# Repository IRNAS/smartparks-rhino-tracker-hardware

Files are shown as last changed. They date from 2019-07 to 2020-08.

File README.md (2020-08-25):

# Smart Parks Rhino Tracker Hardware
 

<br>

Device is composed from 3 different PCBs thah are stacked in to box like shape.

Stackup of PCBs is in this order:
- GPS (Top PCB)					Size: 28mm x 20mm 
- MCU (Side PCB)				Size: 28mm x 20mm (After final assembly)
- LORA ANTENNA (Side PCB)		Size: 28mm x 15.5mm
- BATTERY (Between side PCBs)

PCB specifications:
- 0.8mm PCB thinknes
- 0.152mm (6mil) trace to trace and trace to polygon clearance
- 0.75mm RF line thinknes

Connections between PCBs:
- MCU -> GPS - Solder pads on each PCB
- MCU -> LORA antenna - Coaxial cable

Assebled view
 
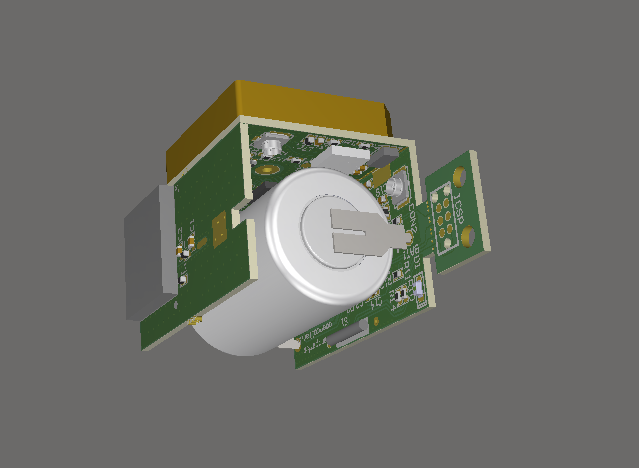
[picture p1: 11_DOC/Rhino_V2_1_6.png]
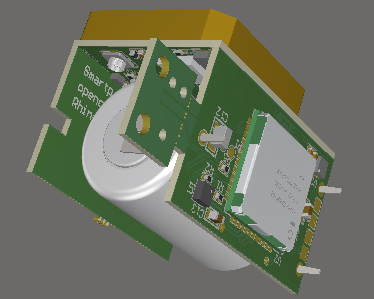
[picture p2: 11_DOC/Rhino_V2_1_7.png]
						

Exploded view
 
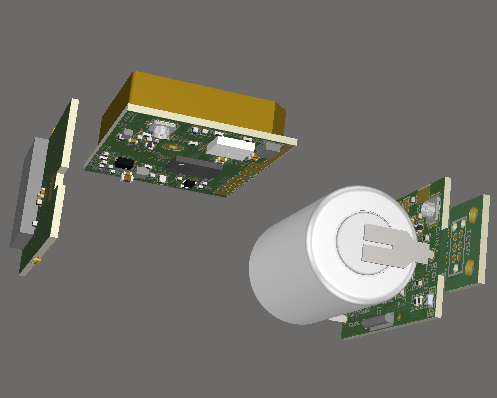
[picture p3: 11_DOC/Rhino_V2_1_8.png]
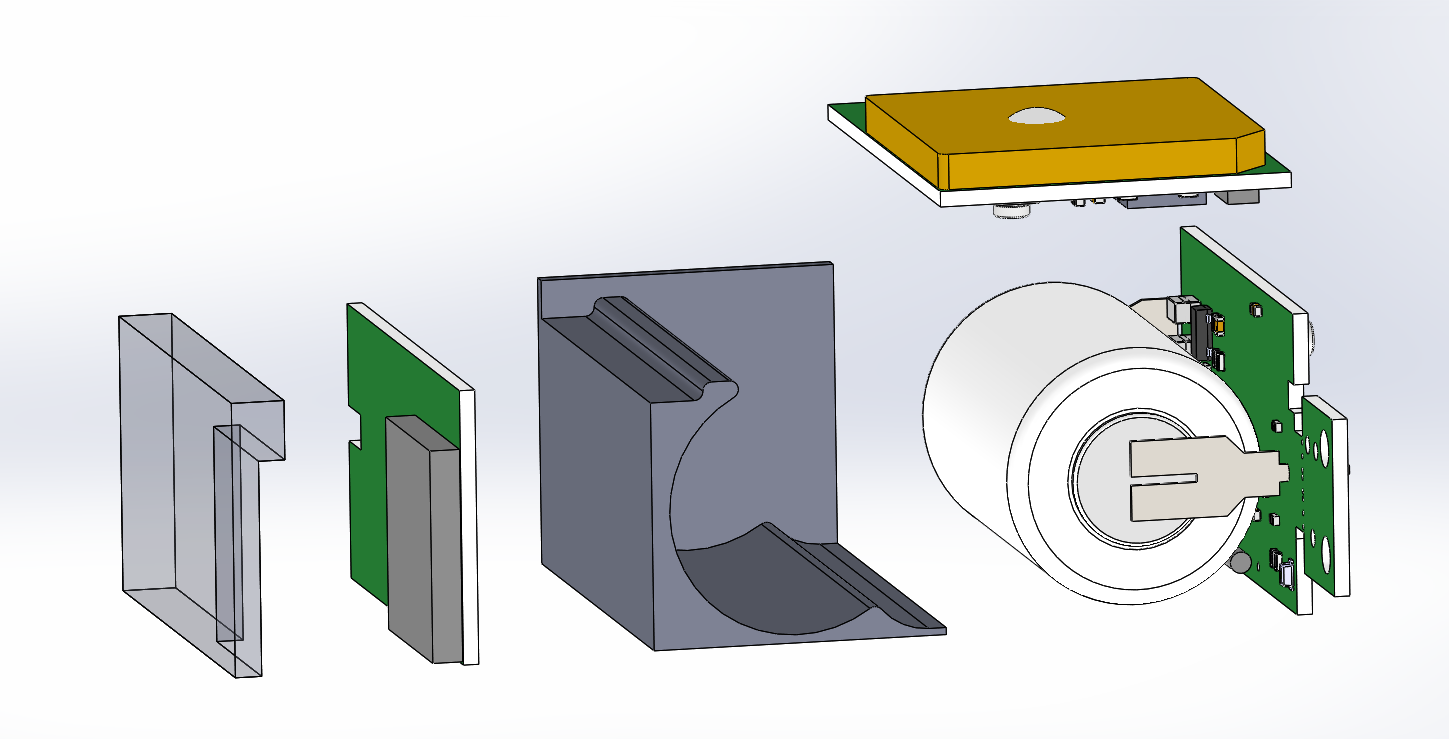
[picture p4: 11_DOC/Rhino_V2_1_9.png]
			

Future changes:
- GPS
	- Reposition of GPS antenna to the center of the PCB
	- Better power supply for GPS (Lower working voltage)
	- Improve GND polygon for better GPS antenna performance	
	
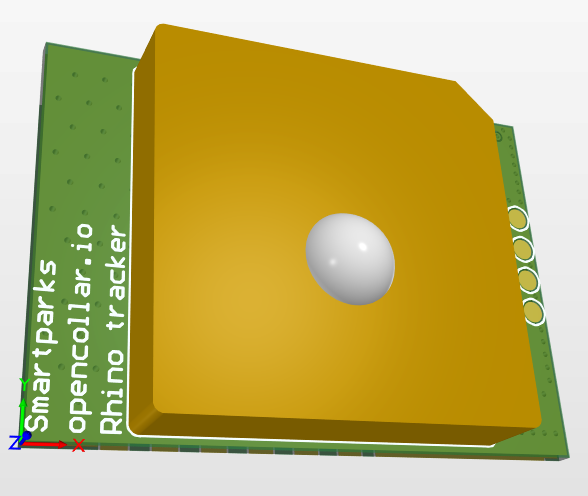
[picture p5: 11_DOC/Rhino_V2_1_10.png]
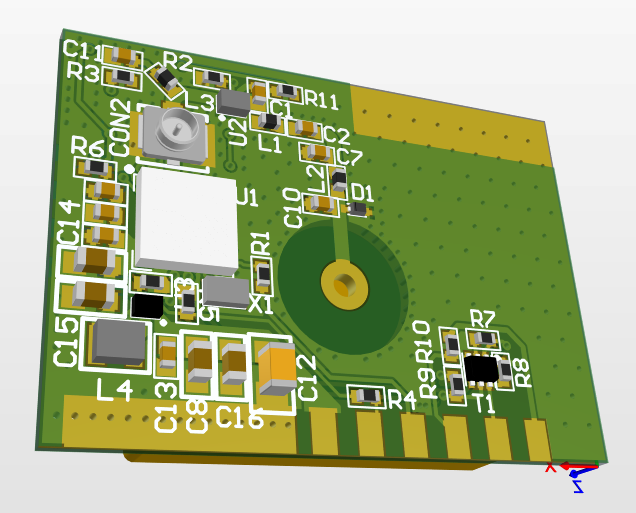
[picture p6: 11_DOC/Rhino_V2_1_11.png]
						

- MCU
	- Optimize track path for antenna
	- Change PCB orientation in final assembly like so that MCU is under battery
	- Optimize hardware for battery voltage measure
	- Move REED switch closer to the MCU
	
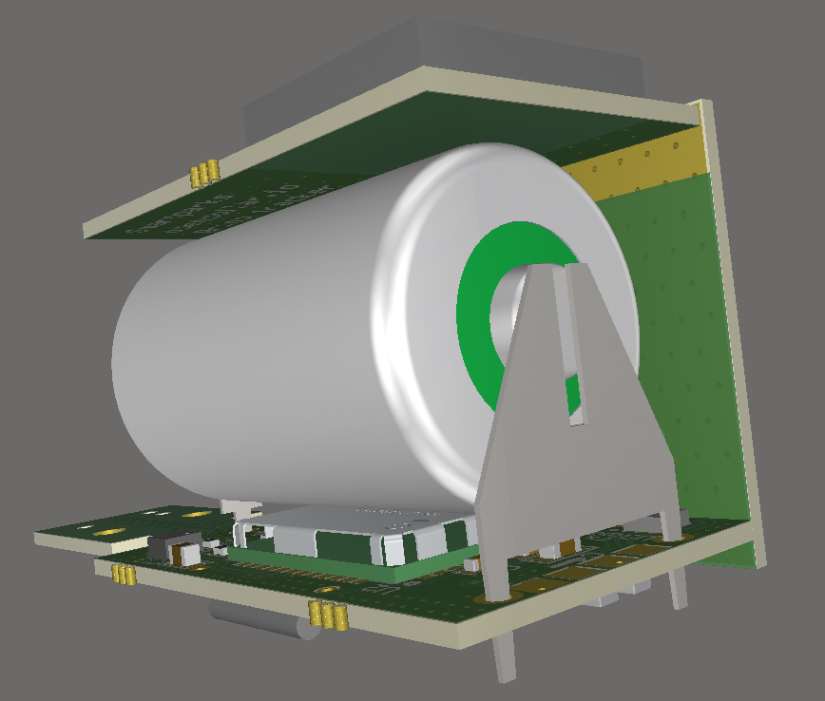
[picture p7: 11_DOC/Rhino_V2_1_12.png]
		
		
- LORA ANTENNA
	- Component value optimization for better antenna performance
 	
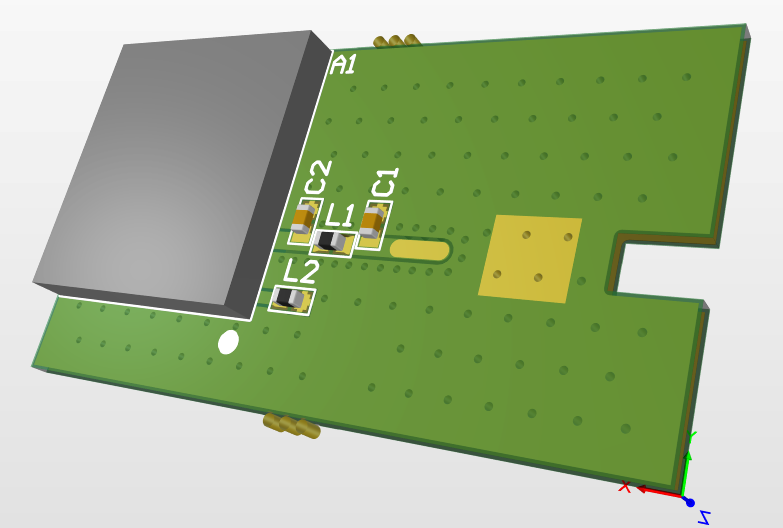
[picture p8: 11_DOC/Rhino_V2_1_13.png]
		

- Mehanical Specification:
	- Device dimensions 32x24x27mm
	- Device weight: ~30g
	- Device is put in polyurethane resin to protect it (https://electrolube.com/product/ur5528-chemically-resistant-polyurethane-resin/)
	- Inside of the device and around the battery there is pa peace of plastic for:
		- Keeping the gap between battery na LORA antenna eqalu on all devices assebled
		- Preventing the resin to go under the MCU metal case (There was a problem with RF radio when resin came under matel case of MCU)
		- Preventing the resin to go under GPS BGA chip (There was a problem when resin came under BGA and coused cold solder joints)
	- Resin thinknes arount the device is 2mm	

Currently under development, for all information see the [schematic PDF file](https://github.com/IRNAS/smartparks-rhino-tracker-hardware/blob/master/10_OUTPUT_FILES/).Produced board versions can be found in the [release section](https://github.com/IRNAS/smartparks-rhino-tracker-hardware/releases) of the repository.

**Latest release: [v2.5](https://github.com/IRNAS/smartparks-rhino-tracker-hardware)**

All comments and suggestions can be added to the [Issues]() section of the repo. For additional details see the [Issue]() section.

---

## Licensing

Rhino tracker hardware with documentation is licensed under [CERN OHL v.1.2. license](https://www.ohwr.org/licenses/cern-ohl/license_versions/v1.2).

What this means is that you can use this hardware and documentation without paying a royalty and knowing that you'll be able to use your version forever. You are also free to make changes but if you share these changes then you have to do so on the same conditions that you enjoy.

IRNAS is name and mark of Institute IRNAS Rače. You may use these name and terms only to attribute the appropriate entity as required by the Open Licence referred to above. You may not use them in any other way and in particular you may not use them to imply endorsement or authorization of any hardware that you design, make or sell.

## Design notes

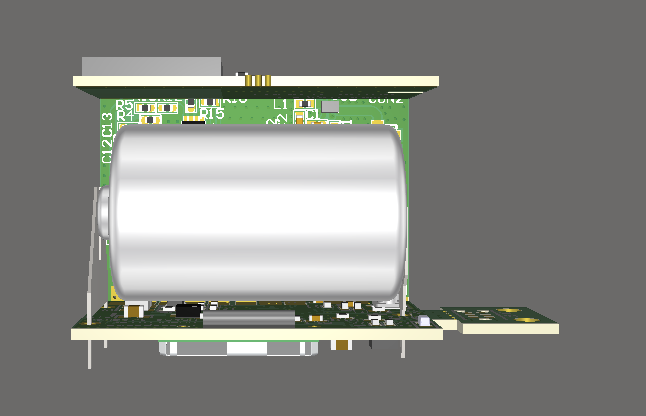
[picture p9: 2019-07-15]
11_DOC/Rhino_V2_1_1.png

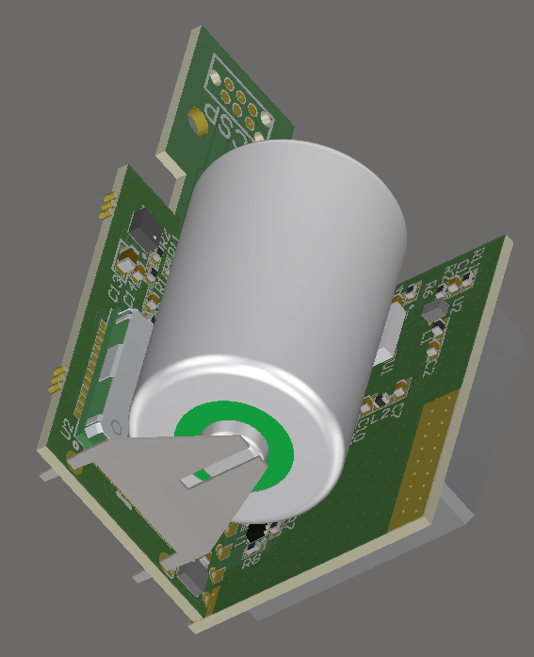
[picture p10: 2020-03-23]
11_DOC/Rhino Tracker 1.png

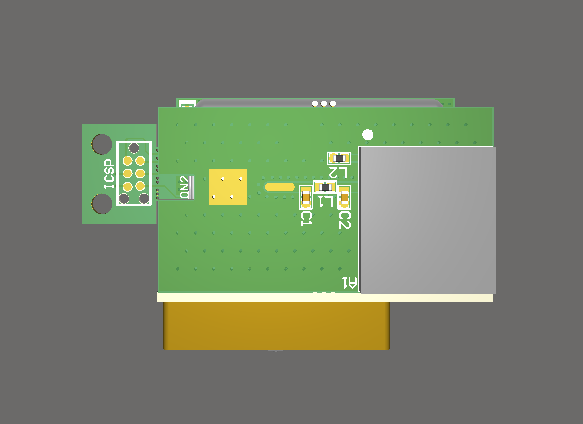
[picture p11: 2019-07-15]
11_DOC/Rhino_V2_1_5.png

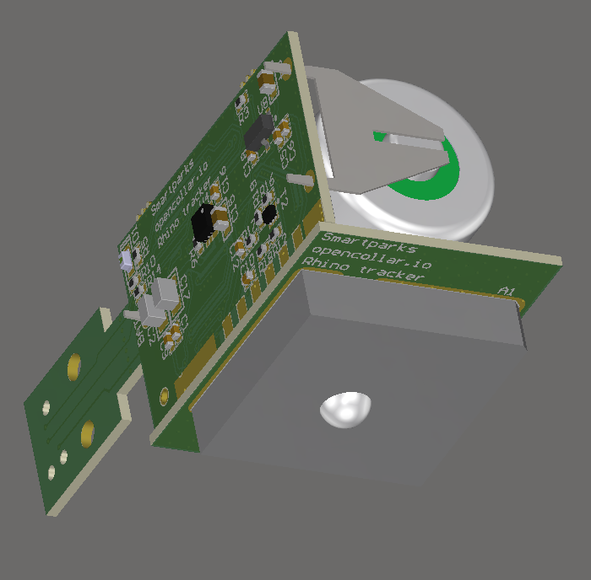
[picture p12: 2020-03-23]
11_DOC/Rhino Tracker 2.png

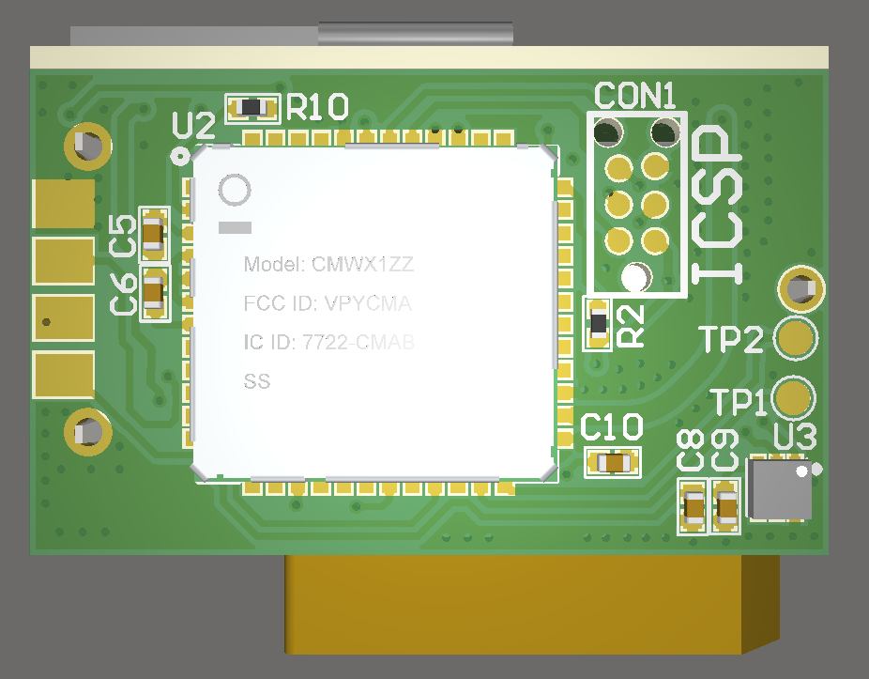
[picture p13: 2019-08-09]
02_MCU/04_OUTPUT_FILES/Rhino_V2_P3.png

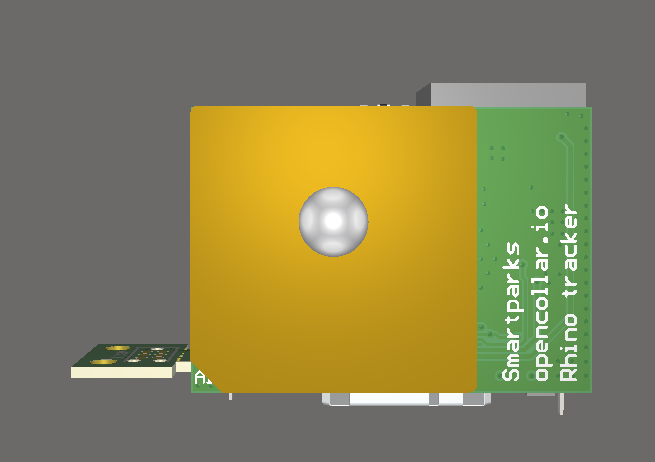
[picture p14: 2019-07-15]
11_DOC/Rhino_V2_1_2.png

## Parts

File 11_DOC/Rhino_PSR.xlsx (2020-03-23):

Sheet: Request
 | Civil Electronics Division Product Specification Request
1. Project Information
Project Designation / Reference | Rhino tracker |  |  |  |  |  |  |  |  |  | Date of Issue |  | 2019-09-03
Customer Account | IRNAS |  |  |  |  |  |  |  |  |  | Slovenia
Customer Contact | Luka |  |  |  | Mustafa |  |  |  |  |  | Phone
 | musti@irnas.eu
 | Valvasorjeva ulica 42 |  |  |  |  |  |  |  | Maribor
 | 2000 |  |  |  |  |  |  |  | Maribor
Current Status of the Project | Develoment Stage |  |  |  |  |  |  |  |  |  | Confidentiality |  | Not Confidential
2. Commercial Information
Expected Quantity Required | Total | pcs | First Year | Quantity |  | pcs | Ramp Up | Quantity |  | pcs |  | Per Batch | Quantity |  | pcs
Expected Battery Price | Price |  |  | Euro |  |  | Competitor
Delivery Schedule | Full Production |  |  | dd/mm/yyyy
Proposal Deliverables | Preliminary Cost |  |  |  |  |  | Technical Proposal
 | Solution Identification |  |  |  |  |  | Interface Drawing |  |  |  |  |  | 3D File | No
 | Prototypes |  |  | No |  |  |  |  |  |  |  |  | File Format
 |  | Quantity |  |  |  |  | Prototypes Delivery Date |  |  | dd/mm/yyyy
3. Application Information
Market |  |  |  |  |  |  |  | Application
Describe your Application | Text
Application Environmental Conditions
Device General Location | Outdoor |  |  |  | Temperature |  | 25 |  | °C |  | 0 | °C | 45 | °C
 | Temperature |  | 25 | °C | 8.3 | °C | 16.6 | °C | 25 | °C | 31.7 | °C | 38.4 | °C | 45
 | Percentage |  | 100 | % |  | % |  | % |  | % |  | % |  | %
Example of Device Location Climate | Johannesburg |  |  |  | City |  |  |  | City |  |  |  | Other
Particular Environmental Conditions | Explosive Atmosphere |  |  | No |  |  |  | Temperature Classification
Applicable Standards | Military Standards |  |  | No
 | Medical Standards |  |  | No
 | CE Marking |  |  | Yes |  | Safety Standards Certification |  |  |  | No
 | Other Standards or Complementary Informations
Device Operational Profile
Description of Device's Life | Minimum Expected Life Duration |  |  |  |  |  |  |  | year |  |  | Sheets "Life" & "Function" could help to fulfill this section
 | Minimum Autonomy during Usage |  |  |  |  | 2 |  |  | year
 | Electronics Operating Voltage Range |  |  |  |  |  | Minimum |  | 2.60 | V | Maximum |  | 3.6 | V
Device Consumption | Operation |  | Average Consumption |  | Duration |  |  | Every |  |  |  | Max Peak Level
Kind of Consumption of the Device | Current Consumption
Device OFF (under storage) | Sleep mode |  | 3 | µA | 1 | h |  |  | All units can be modified with picklists
Device ON | Standby mode |  | 0 | µA | 0 | mn |  |  |  | h
Function #1 ("Funtion Example" table if needed) | Measurement |  | 25 | mA | 10 | s |  |  |  | day |  |  |  | A
Function #2 ("Funtion Example" table if needed) | Communication |  | 20 | mA | 200 | ms |  |  |  | s |  |  |  | A
Function #3 ("Funtion Example" table if needed) |  |  |  | mA |  | mn |  |  |  | s |  |  |  | A
Function #4 ("Funtion Example" table if needed) |  |  |  | mA |  | mn |  |  |  | s |  |  |  | A
Please Enclose Details if Needed | Complementary Information / Additional details on function and/or profile
Total Consumption | 1.3 |  | Ah | Total Consumption is calculated via "Calculation tool" Sheet which can be modified if needed
4. Battery Requirements
Battery Type | Non-Replaceable Battery
Battery Technology | Primary
 | Type of Use |  | Discharged (Battery Permanently Discharge Without Charge Possibility)
 |  |  |  |  |  |  |  |  |  |  |  |  |  | Unit
 |  |  |  |  |  |  |  |  |  |  | Additional Details
Battery Storage | 6 |  | month |  | Temperature |  | 22 |  |  | °C | 0 | °C | 45 | °C
Battery Expected Nominal Voltage | 3.6 |  | V
Available Space for Battery in the Device | Interface Drawing Provided |  |  | No |  |  |  |  | Maximum Available Dimensions
 | 3D File Provided |  |  | No |  |  |  |  | Length |  |  | mm
 |  |  |  |  |  |  |  |  | Width |  |  | mm
 |  |  |  |  |  |  |  |  | Height |  |  | mm
 |  |  |  |  |  |  |  |  | Diameter |  |  | mm
Battery Finishing Requirements | Battery Electrical Connection to the Device |  |  |  |  | Welded on PCB
 |  | Cell Tabbing Arrangements |  |  |  | 3 PF RP
 |  |  |  |  |  |  | mm
 |  |  |  |  |  |  | Type / Reference
 | Maximum Acceptable Weight |  |  |  |  |  | g
 | Battery Pack Final Casing
Packaging & Labelling | Text
 | State of Charge Indicator with Button and LED
 | Smart State of Charge/State of Health Indicator |  |  |  |  |  |  |  | Button + LED
 |  |  |  |  |  |  |  |  | Communication Bus |  |  |  |  | Text
 | Cells Balancing Inside Battery Pack
 | Charger to be Recommended
5. Additional Information
Top Priority Requirements | Priority Number 1
 | Priority Number 2
 | Priority Number 3
Notes | Text

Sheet: Calculation tool
Power Budget Calculation Tool
 |  |  |  |  | Voltage Range of the Application
 |  |  |  |  | Nominal | 3.60 | V
 |  |  |  |  | Minimum | 2.60 | V
 |  |  |  |  | Maximum | 3.60 | V
 |  |  | Current from the Application |  | Pulse Duration |  | Pulse Period |  | Comments | Pulse | Duration corrected |  | Unit | Max peak
 |  | Background | 3 | µA |  |  |  |  |  | 3 | period | correction | µA | 3 | µA
 | Pulse Drains | Pulse 1 | 25 | mA | 10 | s | 1 | h |  | 25000 | 3600 | 10 | mA | 25000 | mA
 |  | Pulse 2 | 20 | mA | 200 | ms | 1 | h |  | 20000 | 3600 | 0.2 | mA | 20000 | mA
 |  | Pulse 3 | 0 | mA | 0 | mn | 0 | s |  | 0 | 0 | 0 | mA
 |  | Pulse 4 | 0 | mA | 0 | mn | 0 | s |  | 0 | 0 | 0 | mA
 |  | Pulse 5 | 0 | µA | 0 | s | 0 | s |  | 0 | 0 | 0 | µA
 |  | Pulse 6 | 0 | mA | 0 | s | 0 | s |  | 0 | 0 | 0 | mA
 |  | Pulse 7 | 0 | mA | 0 | s | 0 | s |  | 0 | 0 | 0 | mA
 |  | Pulse 8 | 0 | mA | 0 | s | 0 | s |  | 0 | 0 | 0 | mA
 |  | Pulse 9 | 0 | mA | 0 | s | 0 | s |  | 0 | 0 | 0 | mA
 |  | Pulse 10 | 0 | mA | 0 | s | 0 | s |  | 0 | 0 | 0 | mA |  |  | 5
 | Maximum Peak |  | 25 | mA |  |  |  |  |  |  |  |  | 1 | 25000 | mA | 6
 |  |  | Application |  |  |  |  |  |  |  |  |  |  |  |  | 6
 |  |  | Equivalent Average Current Consumption during Storage |  |  |  |  | 3 | µA |  |  |  |  |  |  | 6
 |  |  | Storage Duration |  |  |  |  | 1 | h |  |  |  |  |  |  | 6
 |  |  | Storage Power Budget |  |  |  |  | 0.003 | mAh |  |  |  |  |  |  | 7
 |  |  | Equivalent Average Current Consumption during Usage |  |  |  |  | 73.54705556 | µA |  |  |  |  |  |  | 7
 |  |  | Expected Autonomy |  |  |  |  | 2 | year |  |  |  |  |  |  | 7
 |  |  | Usage Power Budget |  |  |  |  | 1288.544413 | mAh |  |  |  |  |  |  | 7
 |  |  | Total Power Budget |  |  |  |  | 1288.547413 | mAh |  |  |  |  |  |  | 8
 |  |  |  |  |  |  |  |  |  |  |  |  |  |  |  | 8
 |  |  |  |  |  |  |  |  |  |  |  |  |  |  |  | 8
 |  |  |  |  |  |  |  |  |  |  |  |  |  |  |  | 8
 |  |  |  |  |  |  |  |  |  |  |  |  |  |  |  | 9
 |  |  |  |  |  |  |  |  |  |  |  |  |  |  |  | 9
 |  |  |  |  |  |  |  |  |  |  |  |  |  |  |  | 9
 |  |  |  |  |  |  |  |  |  |  |  |  |  |  |  | 9
 |  |  |  |  |  |  |  |  |  |  |  |  |  |  |  | 10
 |  |  |  |  |  |  |  |  |  |  |  |  |  |  |  | 10
 |  |  |  |  |  |  |  |  |  |  |  |  |  |  |  | 10
 |  |  |  |  |  |  |  |  |  |  |  |  |  |  |  | 10
 |  |  |  |  |  |  |  |  |  |  |  |  |  |  |  | 11
 |  |  |  |  |  |  |  |  |  |  |  |  |  |  |  | 11
 |  |  |  |  |  |  |  |  |  |  |  |  |  |  |  | 11
 |  |  |  |  |  |  |  |  |  |  |  |  |  |  |  | 11
 |  |  |  |  |  |  |  |  |  |  |  |  |  |  |  | 12
 |  |  |  |  |  |  |  |  |  |  |  |  |  |  |  | 12
 |  |  |  |  |  |  |  |  |  |  |  |  |  |  |  | 12
 |  |  |  |  |  |  |  |  |  |  |  |  |  |  |  | 12
 |  |  |  |  |  |  |  |  |  |  |  |  |  |  |  | 13
 |  |  |  |  |  |  |  |  |  |  |  |  |  |  |  | 13
 |  |  |  |  |  |  |  |  |  |  |  |  |  |  |  | 13
 |  |  |  |  |  |  |  |  |  |  |  |  |  |  |  | 13
 |  |  |  |  |  |  |  |  |  |  |  |  |  |  |  | 14
 |  |  |  |  |  |  |  |  |  |  |  |  |  |  |  | 14
 |  |  |  |  |  |  |  |  |  |  |  |  |  |  |  | 14
 |  |  |  |  |  |  |  |  |  |  |  |  |  |  |  | 14

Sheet: Market-Application
 | List of Market Segment and relative Applications
Market | Application
Automation & Instrumentation | Controllers
Automation & Instrumentation | Industrial Dataloggers
Automation & Instrumentation | Industrial Robots
Automation & Instrumentation | Measurement Devices
Automation & Instrumentation | Power Grid Transmission & Distribution Devices
Automation & Instrumentation | Tank Monitoring
Automotive | E-Call
Automotive | Tire Pressure Monitoring
Automotive | Telematics
Aviation | Avionics Equipment
Aviation | Unmanned Aircraft Systems
Distributors & EMS | Pack Makers
Distributors & EMS | Retailers
Distributors & EMS | Engineering & Manufacturing Services
Environment Monitoring | Meteorology
Environment Monitoring | Oceanography Equipment
Environment Monitoring | Pollution Monitoring
Environment Monitoring | Seismic Sensors
Environment Monitoring | Woodfire Monitoring
Internet Of Things | Smart Parking
Internet Of Things | Smart Building
Internet Of Things | Environment Monitoring Application
Internet Of Things | Smart Transportation
Internet Of Things | Industrial Application
Internet Of Things | Health & Medical Application
Internet Of Things | Life Analysis Service
Lighting & Signaling | Emergency Lighting Unit
Lighting & Signaling | Street Lighting
Lighting & Signaling | Traffic Lighting
Medical | Automated External Defibrillators
Medical | Infusion Pumps
Medical | Neuro-Stimulation
Medical | Medical Carts
Medical | Respiration & Ventilation
Medical | E Health Devices
Medical | Surgery Tools
Military / Soldier System | Chemical Agent Detectors
Military / Soldier System | Future Soldier Combat Systems
Military / Soldier System | GPS
Military / Soldier System | Ground Radars
Military / Soldier System | Lamps
Military / Soldier System | Laser
Military / Soldier System | Military Robots & Remotely Operated Vehicles
Military / Soldier System | Night Vision Googles
Military / Soldier System | Police Equipment
Military / Soldier System | Radiocommunications
Military / Soldier System | Simulators
Military / Soldier System | UPS Backup
Mining | Mining Lamps
Mining | Underground Mining Machinery
Mining | Miner Portable Devices
Mobility | E-Bike
Mobility | Forklifts
Mobility | Scooters
Mobility | Wheelchairs
Mobility | Caddy
Mobility | Railway
Oil & Gas | Land Seismic Survey System
Oil & Gas | Ocean Seismic Survey Equipment
Oil & Gas | Downhole / Well Instrumentation
Oil & Gas | Oil Drilling Monitoring Sensors (MWD / LWD)
Oil & Gas | Well Completion Tool
Oil & Gas | Pipeline Inspection
Oil & Gas | Digital Oilfield Applications
Other | Consumer Electronics
Other | Research Labs Universities
Professional Power Tools | Power Tools & Professional Portable Devices
Professional Power Tools | Professional Video
Professional Power Tools | Payment Terminals
Professional Power Tools | Professional Computers
Professional Power Tools | Professional Displays
Search & Rescue | ELTs
Search & Rescue | EPIRBS
Search & Rescue | Safety Jackets
Search & Rescue | Buoys
Search & Rescue | Firemen Equipment
Search & Rescue | Parachutes
Search & Rescue | Safety Pyrotechnics Devices
Security | Alarms
Security | Smoke Detectors
Security | Electronic Safes
Security | Safe Locks
Security | Sensors / Detectors
Security | CCTV Surveillance
Security | Cash Protection Systems
Space | Satellites
Space | Launchers
Space | Probes
Space | Rovers
Space | Cargos
Space | Shuttles
Space | International Space Station
Space | Outer Space Experiments
Telecom
Tracking | ETC (Electronic Tollgate Collector)
Tracking | Asset Tracking
Tracking | GPS
Tracking | Road Sensors
Tracking | Animal Tracking
Tracking | RFID
Urban Infrastructures
Utility Metering | Electricity Meters
Utility Metering | Water Meters
Utility Metering | Gas Meters
Utility Metering | Heat Cost Allocators
Utility Metering | Data Concentrators / Gateways
Utility Metering | Communication Modules
Utility Metering | Meters' Life Analysis Service

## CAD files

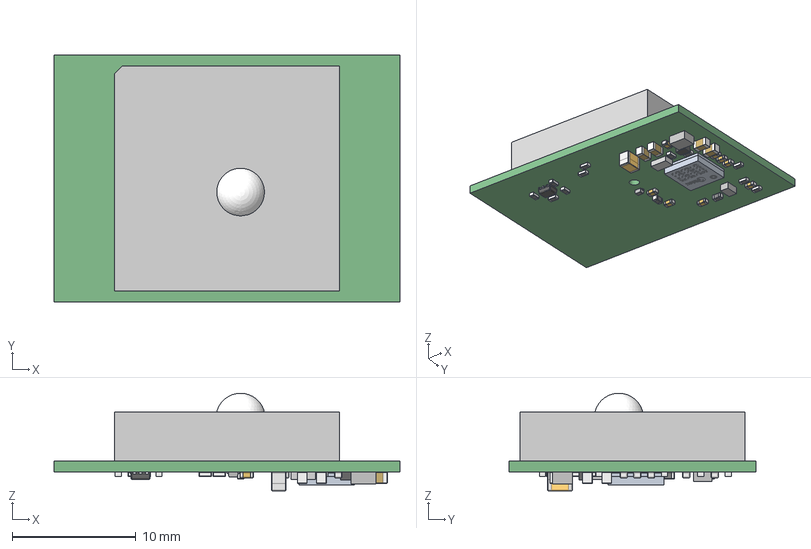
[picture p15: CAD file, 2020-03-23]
01_GPS/06_RELEASE/V2.5/Rhino - GPS_V2.5_3D/Rhino - GPS_V2.5_3D STEP.step
28.0 x 20.0 x 7.89 mm
Extruded x 5
Open_CASCADE_STEP_translator_6.8_4.1.1 x 8
Open_CASCADE_STEP_translator_6.8_4.1.2 x 8
Open_CASCADE_STEP_translator_6.8_4.2.1 x 8
C_SMD_0603 x 4
Mid_Body x 11
Open_CASCADE_STEP_translator_6.8_3.2.1 x 22
Mark x 11
CAPC2012X95N_EIA_0805 x 2
U-Blox_ZOE_S-LGA51_body
u-Blox_ZOE_S-LGA51_ball x 51
SOT-563
Open_CASCADE_STEP_translator_6.8_1.1.1 x 2
Open_CASCADE_STEP_translator_6.8_1.1.2 x 2
Open_CASCADE_STEP_translator_6.8_1.2.1 x 2
SOD-923

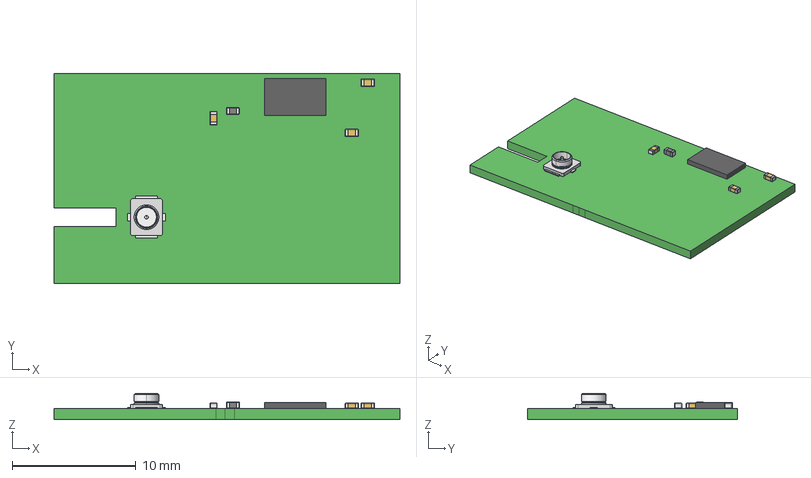
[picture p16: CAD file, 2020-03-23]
03_LORA_ANT/06_RELEASE/V2.0/Rhino - LORA ANT_V2_3D/Rhino - LORA ANT_V2_3D STEP.step
28.0 x 17.0 x 2.14 mm
Open_CASCADE_STEP_translator_6.8_4.1.1 x 3
Open_CASCADE_STEP_translator_6.8_4.1.2 x 3
Open_CASCADE_STEP_translator_6.8_4.2.1 x 3
SW3dPS-UFL-R-SMD_Part_525
SW3dPS-UFL-R-SMD_Part_540
SW3dPS-UFL-R-SMD_Part_739
SW3dPS-UFL-R-SMD_Part_555
SW3dPS-UFL-R-SMD_Part_578
SW3dPS-UFL-R-SMD_Part_562
Open_CASCADE_STEP_translator_6.8_1.1.1
Open_CASCADE_STEP_translator_6.8_1.1.2
Open_CASCADE_STEP_translator_6.8_1.2.1
Extruded

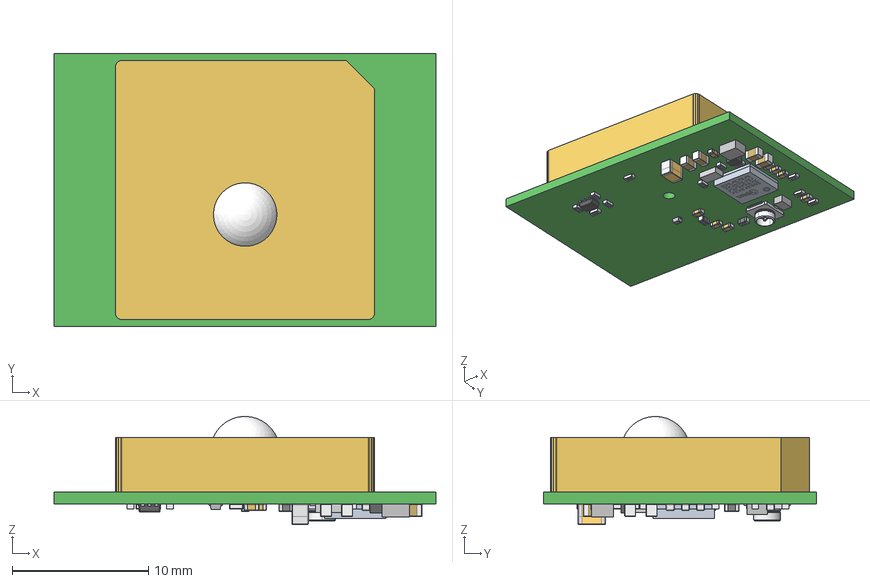
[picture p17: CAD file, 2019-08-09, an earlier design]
01_GPS/06_RELEASE/V2.2/Rhino - GPS_V2.2_3D/Rhino - GPS_V2.2_3D STEP.step
28.0 x 20.0 x 7.93 mm
Open_CASCADE_STEP_translator_6.8_4.1.1 x 8
Open_CASCADE_STEP_translator_6.8_4.1.2 x 8
Open_CASCADE_STEP_translator_6.8_4.2.1 x 8
C_SMD_0603 x 4
Extruded x 5
Mid_Body x 11
Open_CASCADE_STEP_translator_6.8_3.2.1 x 22
Mark x 11
CAPC2012X95N_EIA_0805 x 2
U-Blox_ZOE_S-LGA51_body
u-Blox_ZOE_S-LGA51_ball x 51
SW3dPS-UFL-R-SMD_Part_525
SW3dPS-UFL-R-SMD_Part_540
SW3dPS-UFL-R-SMD_Part_739
SW3dPS-UFL-R-SMD_Part_555
SW3dPS-UFL-R-SMD_Part_578
SW3dPS-UFL-R-SMD_Part_562
SOT-563
Open_CASCADE_STEP_translator_6.8_1.1.1 x 2
Open_CASCADE_STEP_translator_6.8_1.1.2 x 2
Open_CASCADE_STEP_translator_6.8_1.2.1 x 2
SOD-923

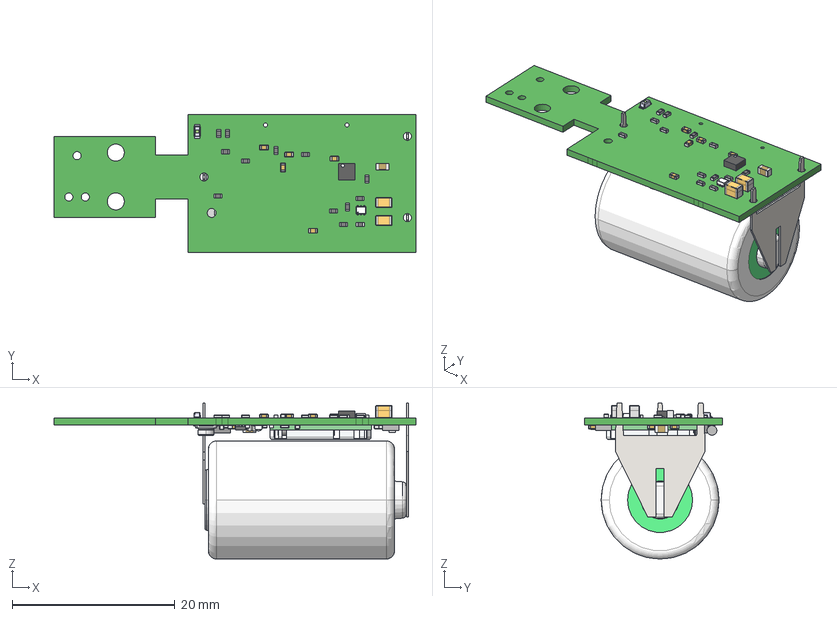
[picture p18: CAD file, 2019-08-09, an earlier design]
02_MCU/06_RELEASE/V2.2/Rhino - MCU_V2.2_3D/Rhino - MCU_V2.2_3D STEP.step
44.5 x 17.0 x 19.2 mm
WCSP6-YFF
HHM-6_1P6X0P8
VMT6_RGB16777215 x 2
Mid_Body x 20
Open_CASCADE_STEP_translator_6.8_3.2.1 x 40
Mark x 20
Open_CASCADE_STEP_translator_6.8_4.1.1 x 11
Open_CASCADE_STEP_translator_6.8_4.1.2 x 11
Open_CASCADE_STEP_translator_6.8_4.2.1 x 11
Open_CASCADE_STEP_translator_6.8_1.1.1 x 2
Open_CASCADE_STEP_translator_6.8_1.1.2 x 2
Open_CASCADE_STEP_translator_6.8_1.2.1 x 2
SW3dPS-UFL-R-SMD_Part_525
SW3dPS-UFL-R-SMD_Part_540
SW3dPS-UFL-R-SMD_Part_739
SW3dPS-UFL-R-SMD_Part_555
SW3dPS-UFL-R-SMD_Part_578
SW3dPS-UFL-R-SMD_Part_562
C_SMD_0603 x 3
User_Library-LS14250_3PF_Extruded_13
User_Library-LS14250_3PF_Extruded_14
User_Library-LS14250_3PF_SAFT_LS14250
Extruded x 11
CMWX1ZZABZ_PCB
CMWX1ZZABZ_Shield
lga-2x2x0_9
LED_SMD_0603
CAPC2012X95N_EIA_0805 x 4

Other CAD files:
01_GPS/06_RELEASE/V2.4/Rhino - GPS_V2.4_3D/Rhino - GPS_V2.4_3D STEP.step

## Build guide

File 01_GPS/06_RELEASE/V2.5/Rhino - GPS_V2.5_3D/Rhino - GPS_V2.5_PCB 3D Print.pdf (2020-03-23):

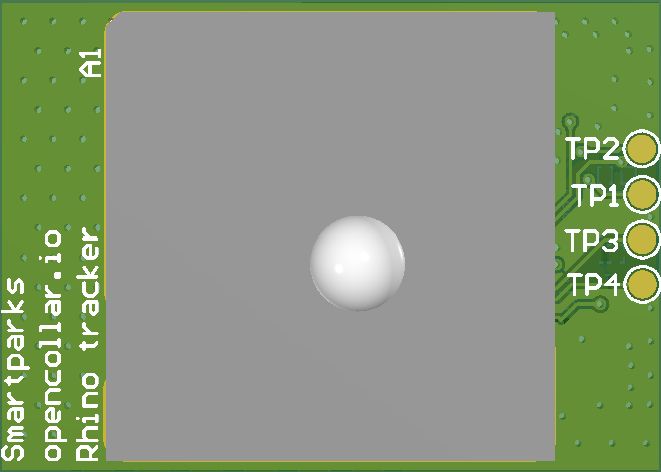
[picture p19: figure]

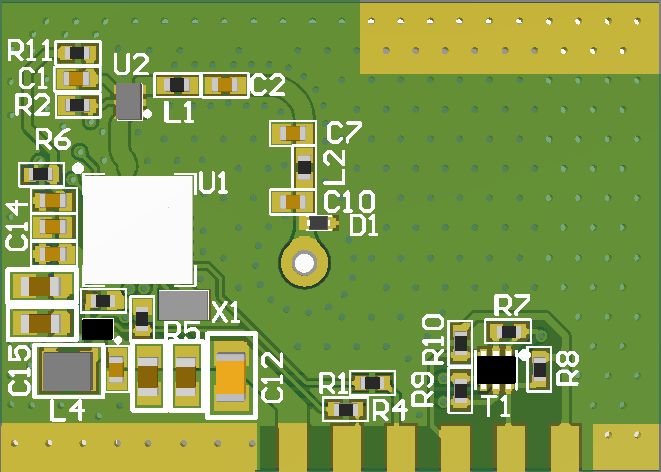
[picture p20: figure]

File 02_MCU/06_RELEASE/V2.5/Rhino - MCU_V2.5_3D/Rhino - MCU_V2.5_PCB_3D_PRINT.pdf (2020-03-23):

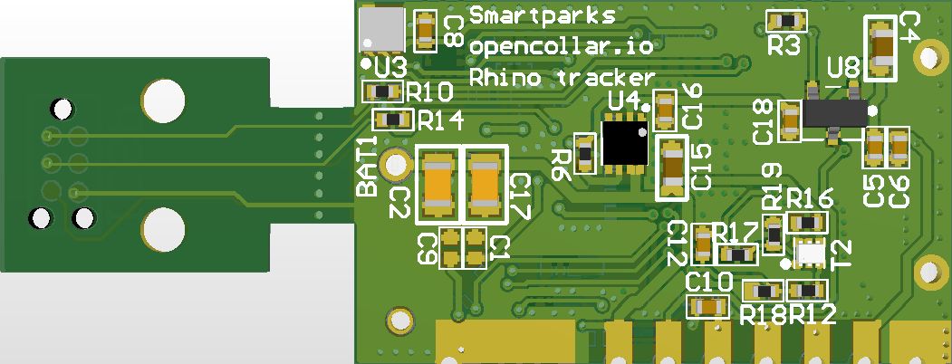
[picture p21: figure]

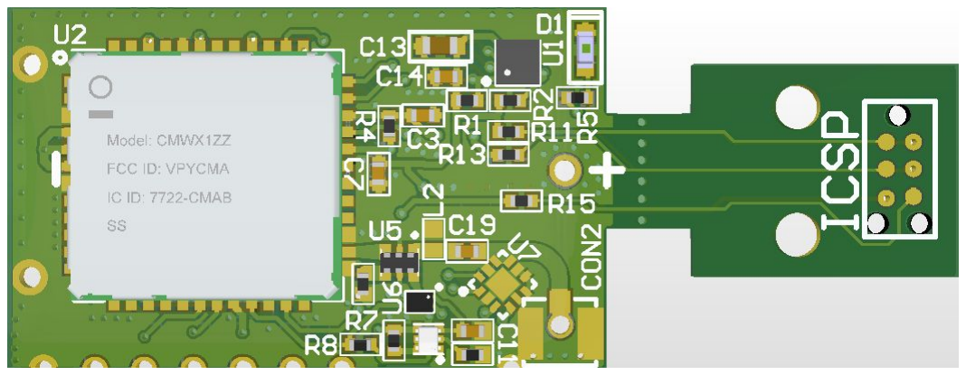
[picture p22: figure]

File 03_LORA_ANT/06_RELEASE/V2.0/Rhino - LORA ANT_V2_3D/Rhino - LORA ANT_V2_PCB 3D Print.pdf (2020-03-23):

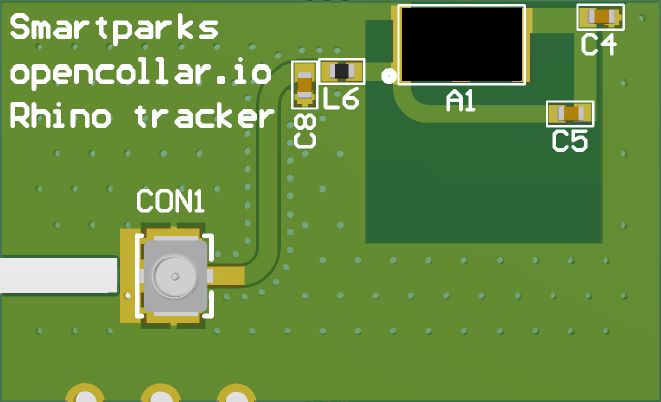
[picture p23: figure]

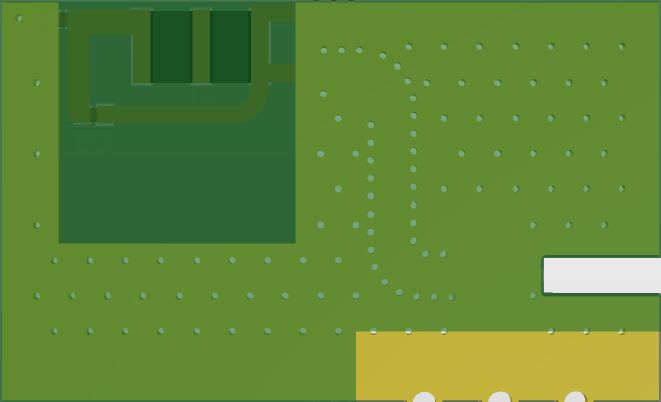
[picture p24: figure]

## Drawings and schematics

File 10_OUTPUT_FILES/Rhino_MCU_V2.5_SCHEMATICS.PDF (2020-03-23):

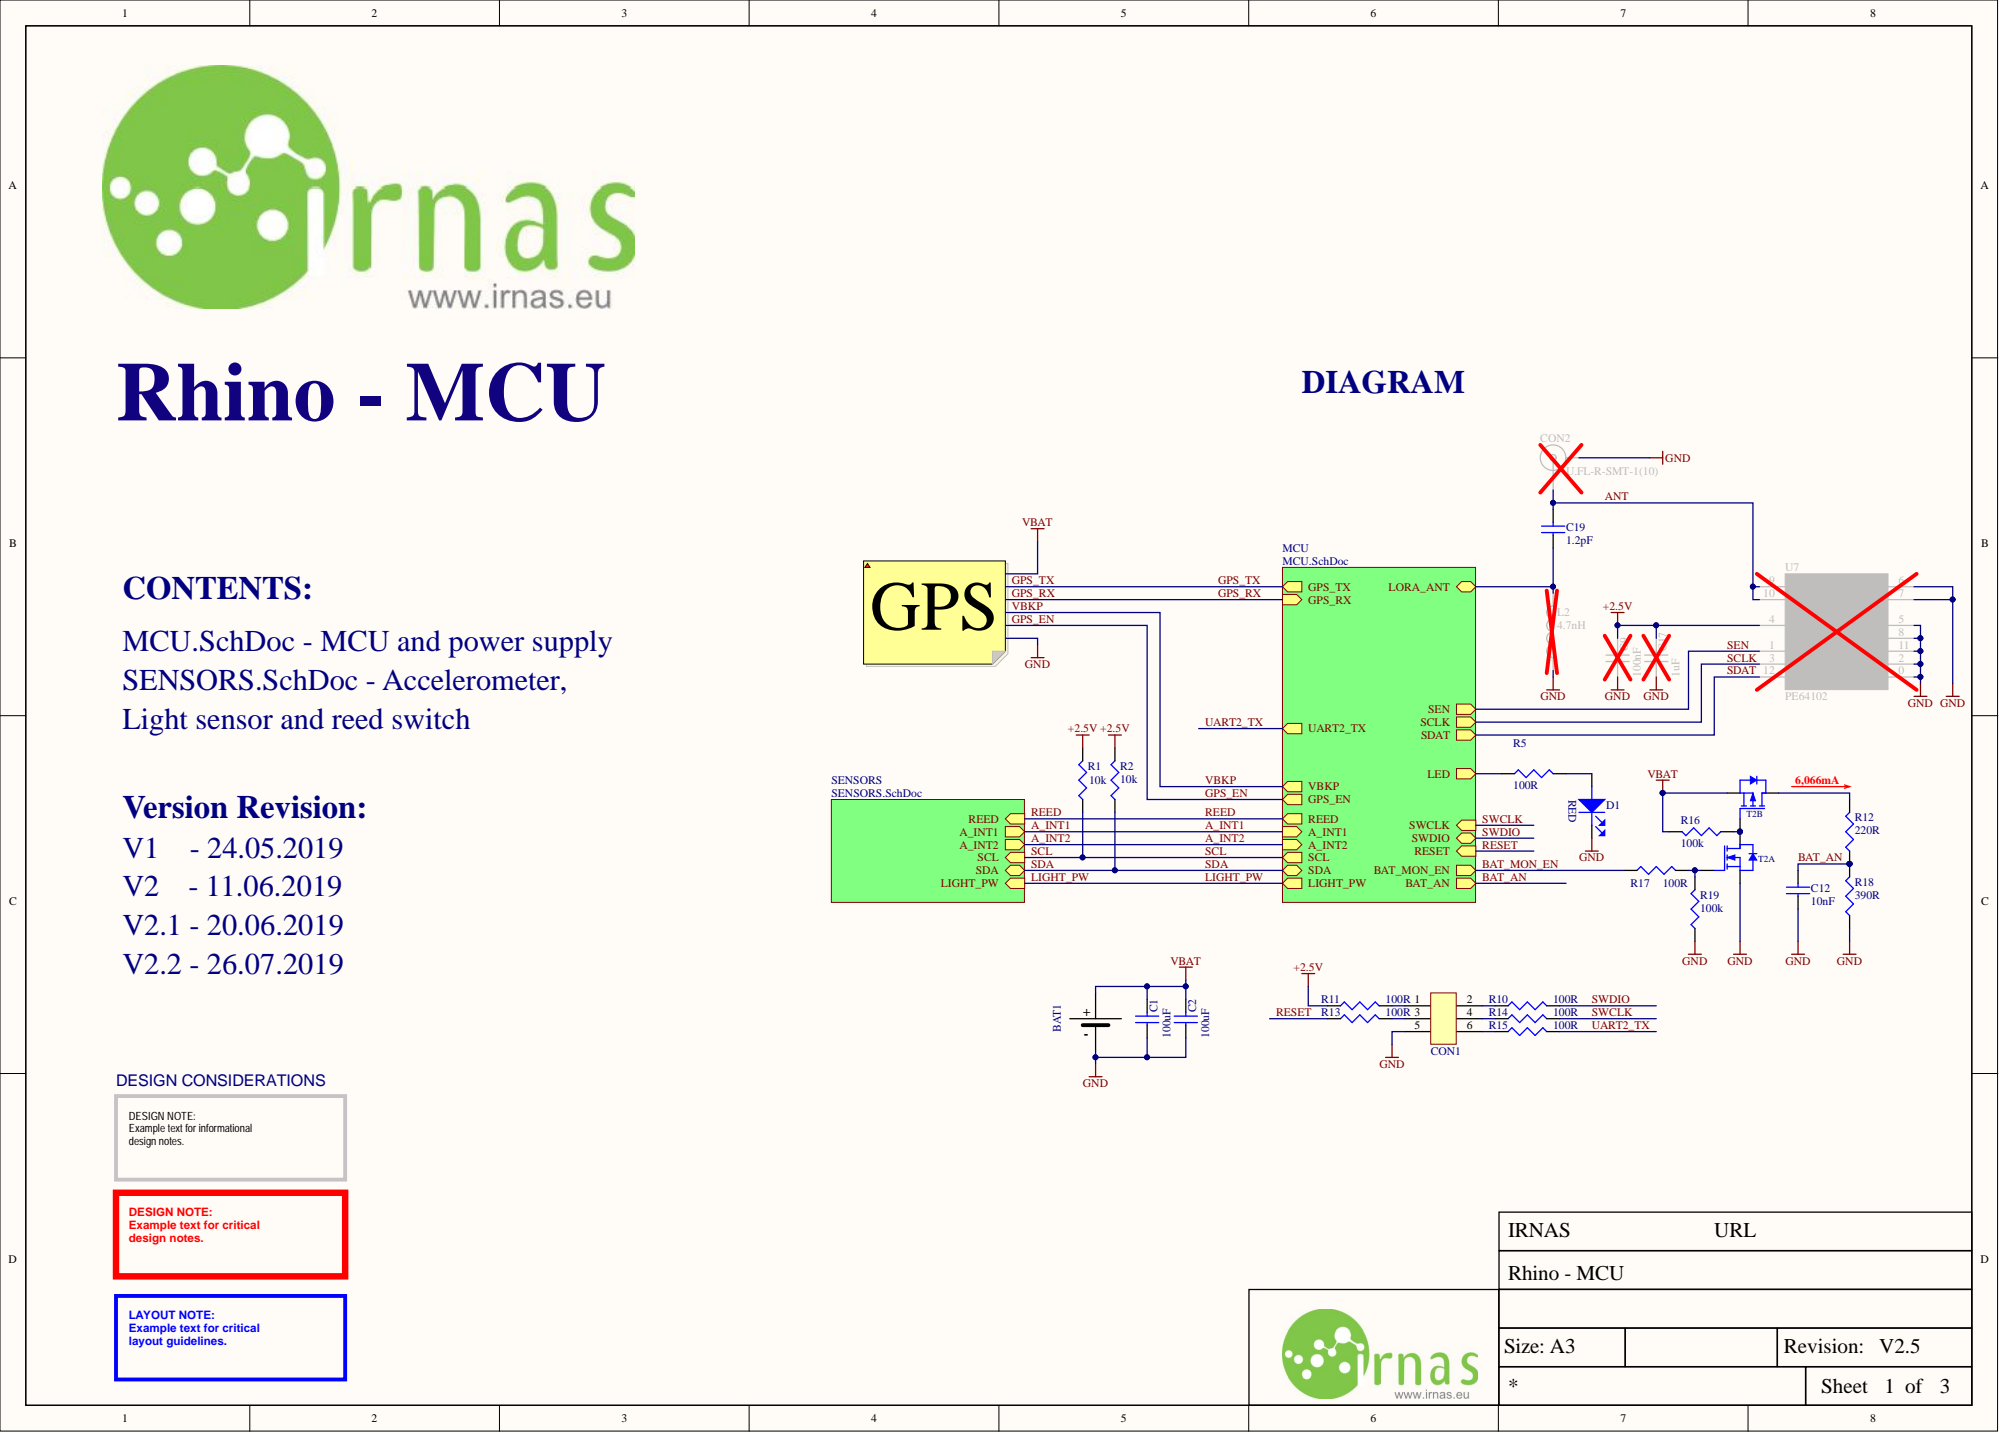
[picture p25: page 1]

MCU.SchDoc - MCU and power supply
SENSORS.SchDoc - Accelerometer,
Light sensor and reed switch

REED A_INT1 A_INT2 SCL SDA LIGHT_PW | REED | REED

A_INT1 | A_INT1
A_INT2 | A_INT2
SCL | SCL
SDA | SDA

DESIGN NOTE:
Example text for informational
design notes.

Example text for critical

LAYOUT NOTE:
layout guidelines.

Size: A3 | | Revision: V2.5

* | Sheet 1 of 3

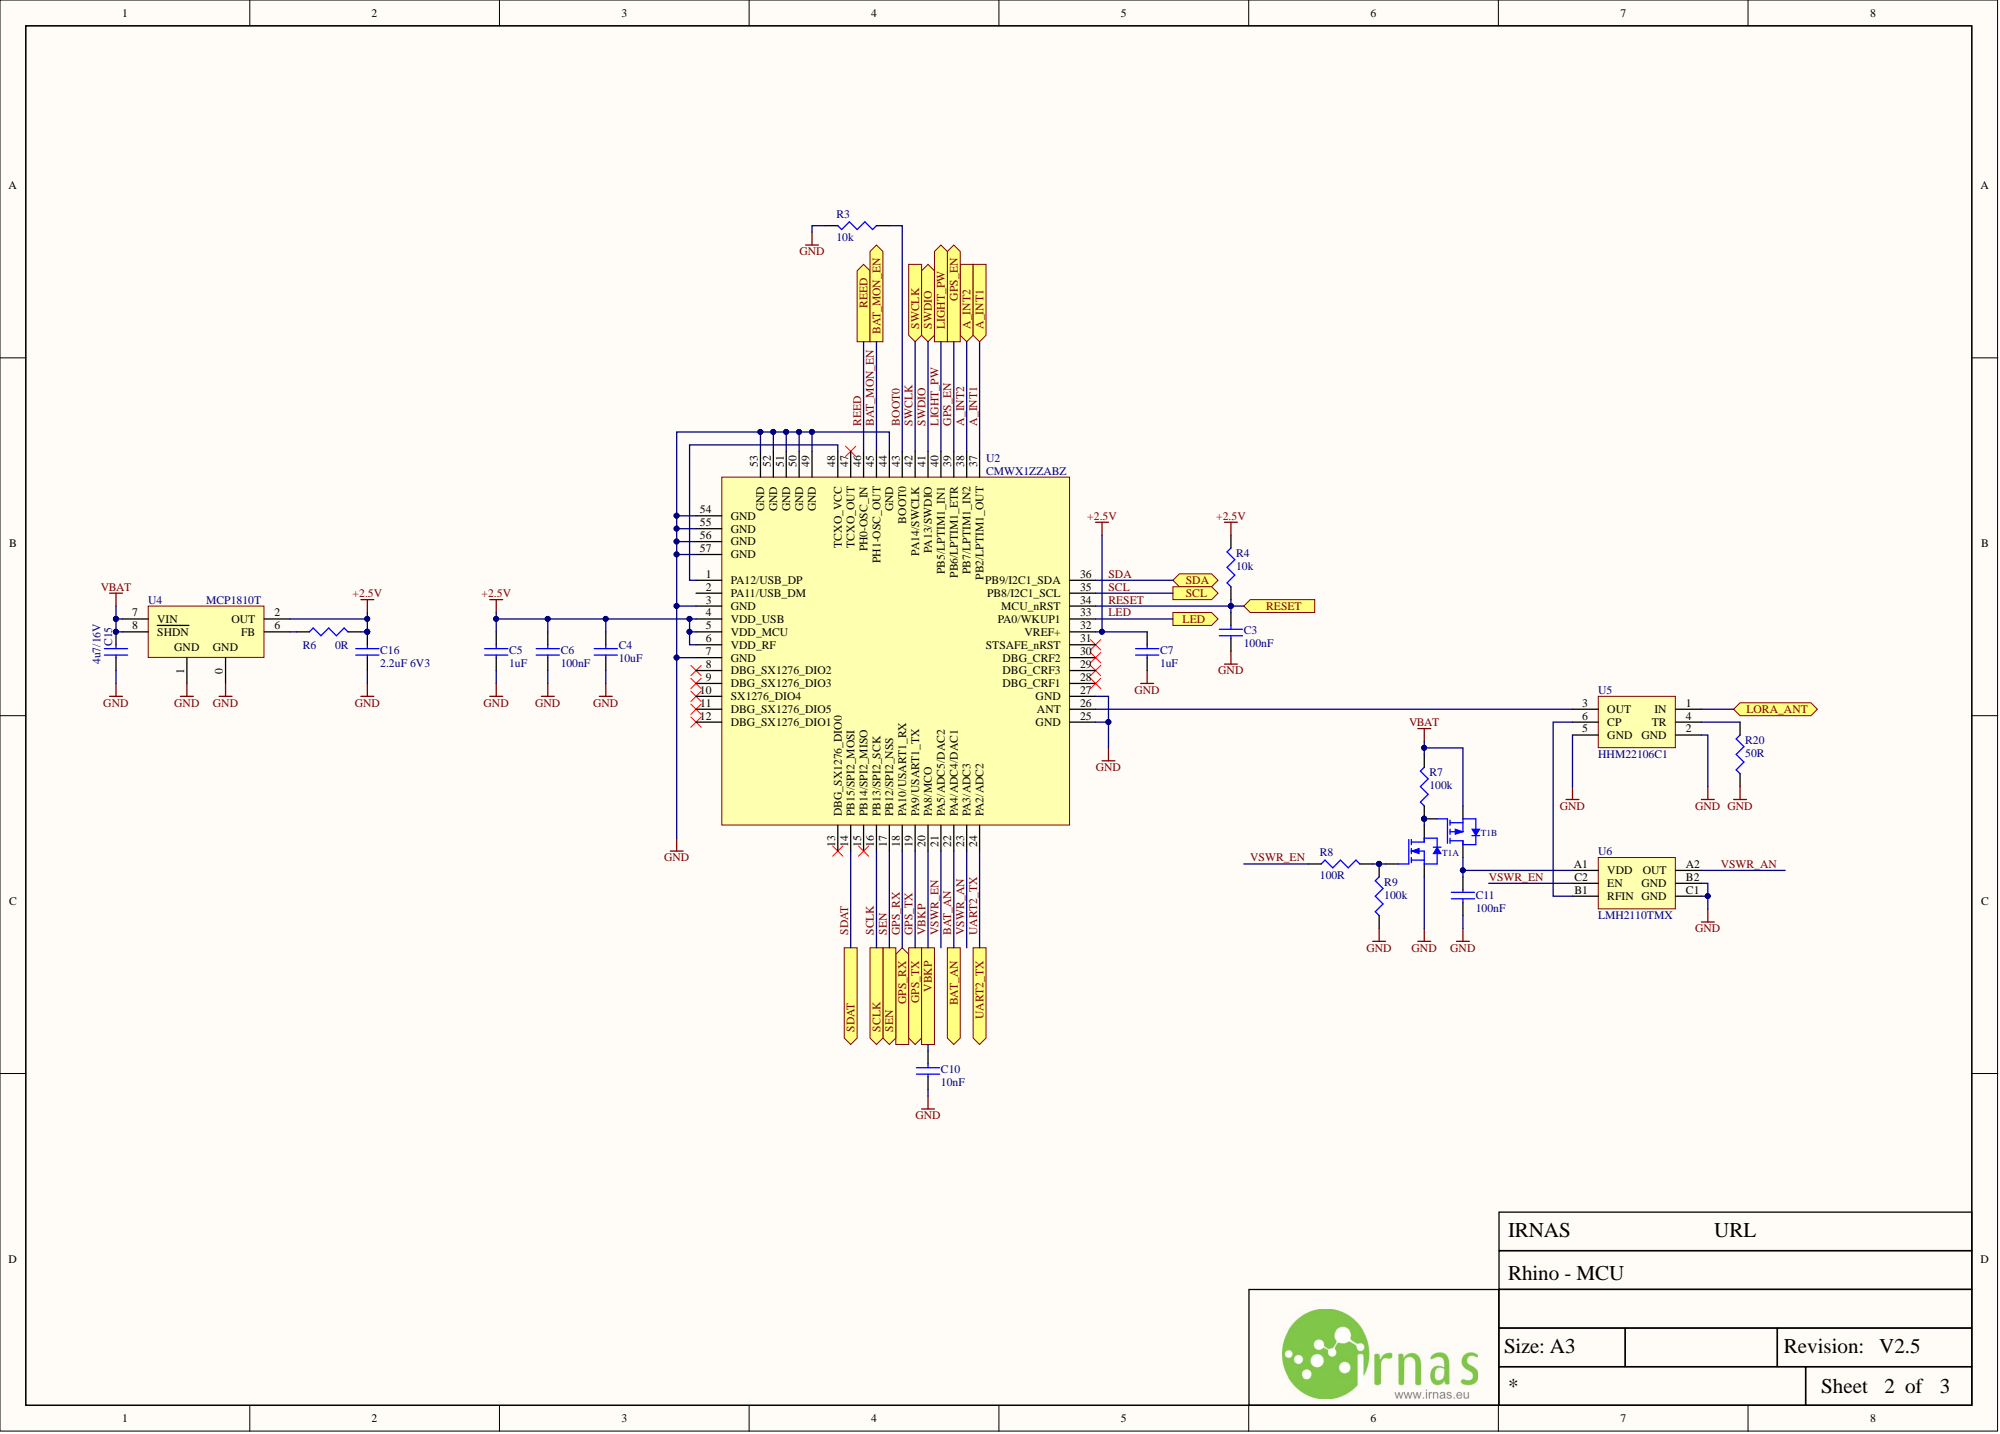
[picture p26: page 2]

GND 50 GND 51 GND 52 GND 53

OUT 37 PB7/LPTIM1_IN2 38 PB6/LPTIM1_ETR 39 PB5/LPTIM1_IN1 40 PA13/SWDIO 41 PA14/SWCLK 42 BOOT0 43 GND 44 PH1-OSC_OUT 45 PH0-OSC_IN 46 TCXO_OUT 47 TCXO_VCC 48

GND 54 | PA0/WKUP1 | 33 MCU_nRST 34 PB8/I2C1_SCL 35 PB9/I2C1_SDA
GND 55
GND 56
GND 57

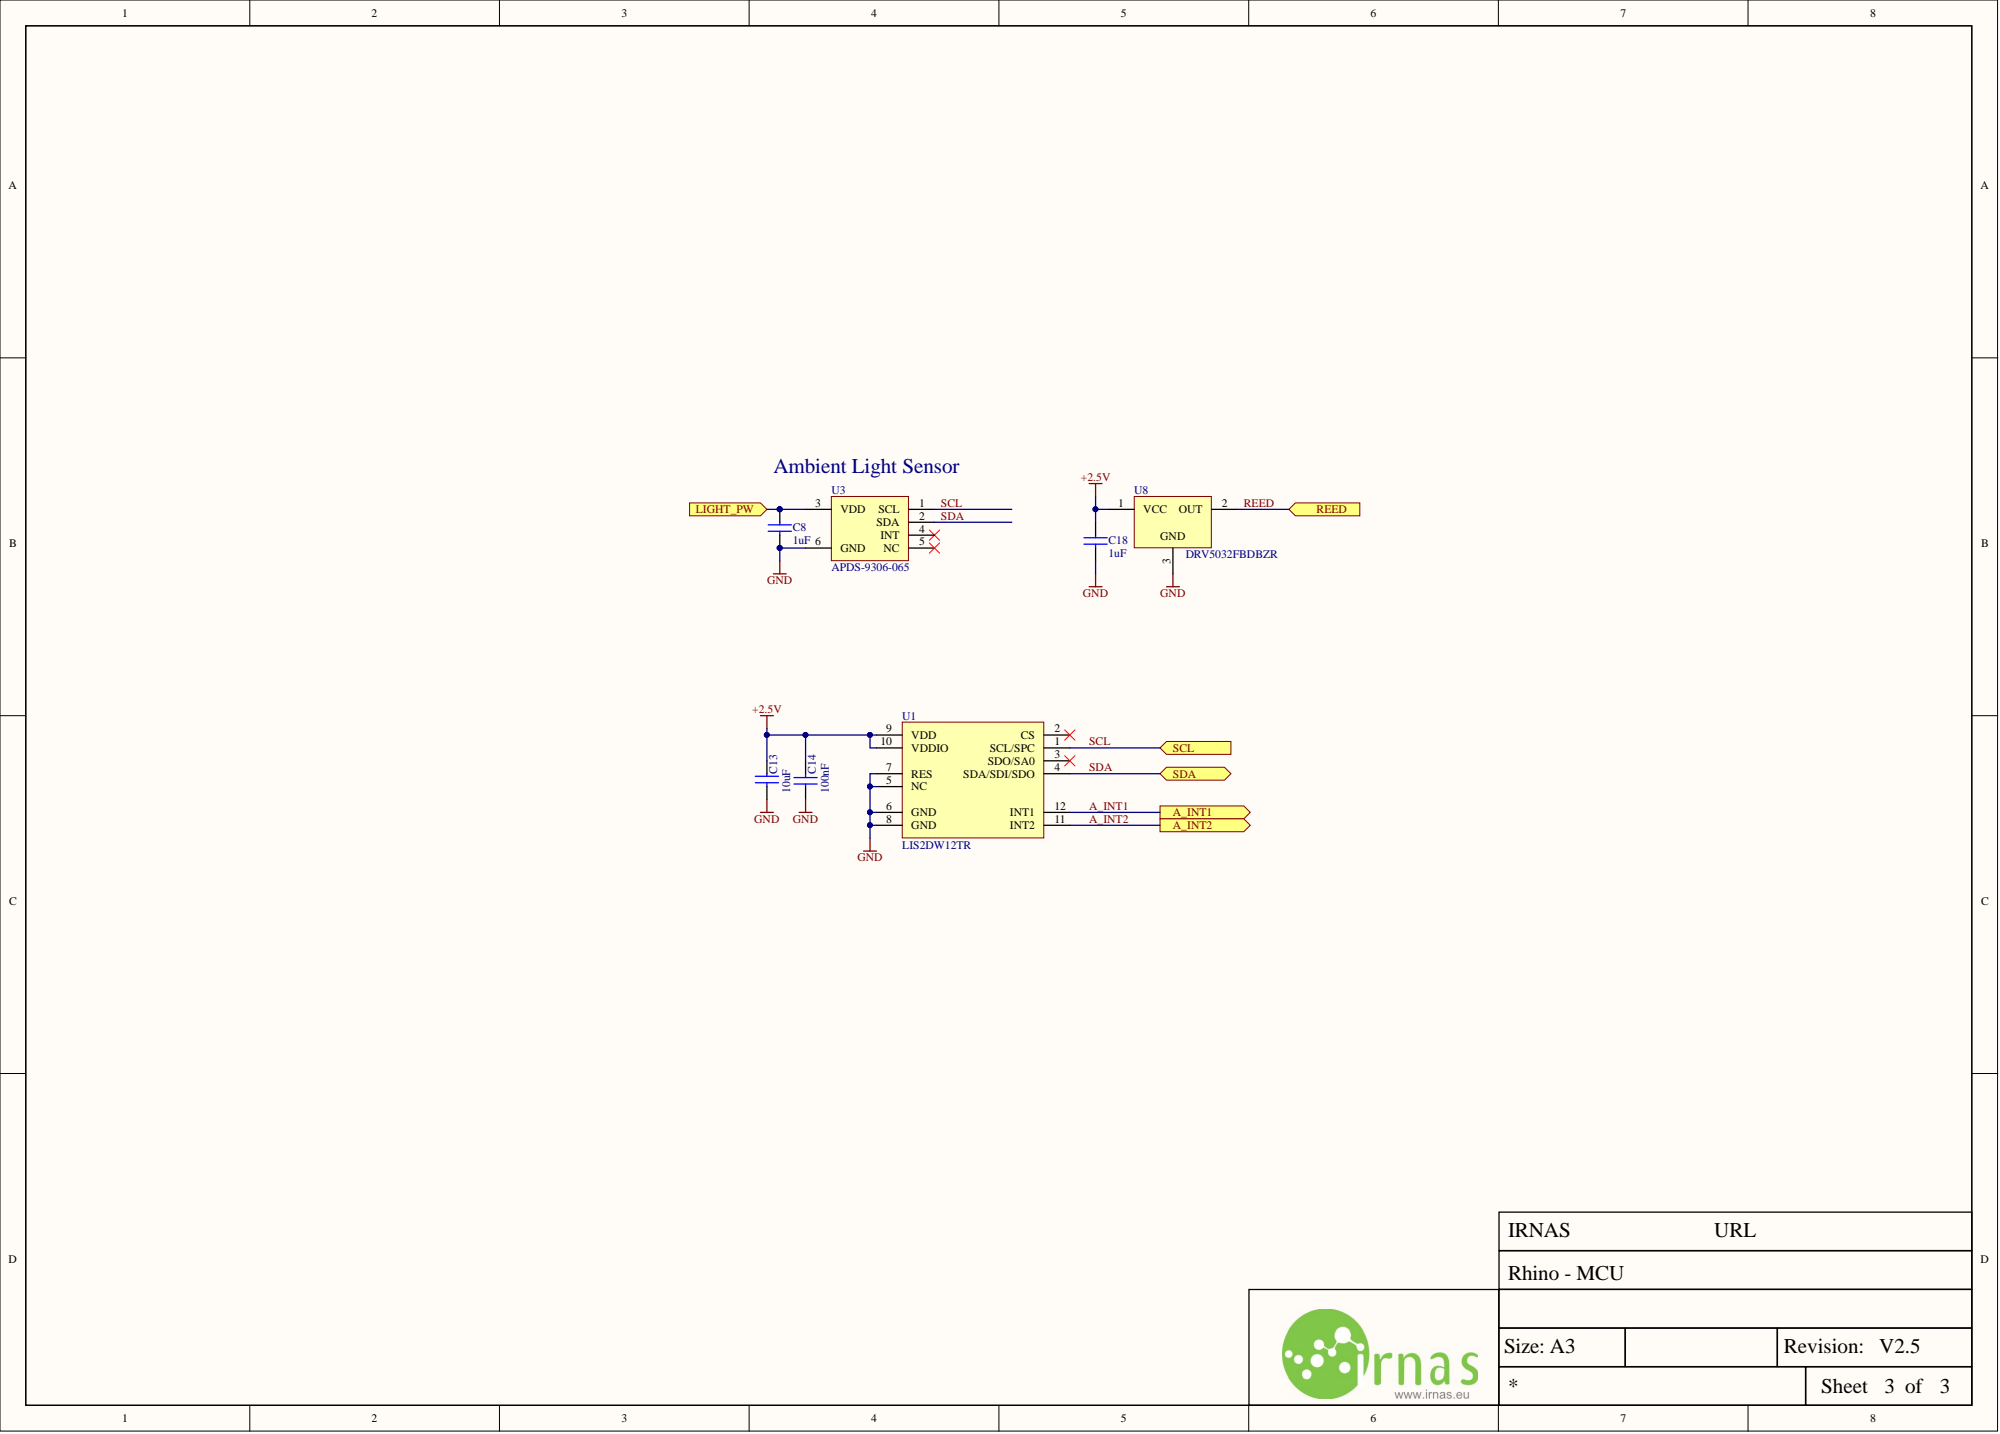
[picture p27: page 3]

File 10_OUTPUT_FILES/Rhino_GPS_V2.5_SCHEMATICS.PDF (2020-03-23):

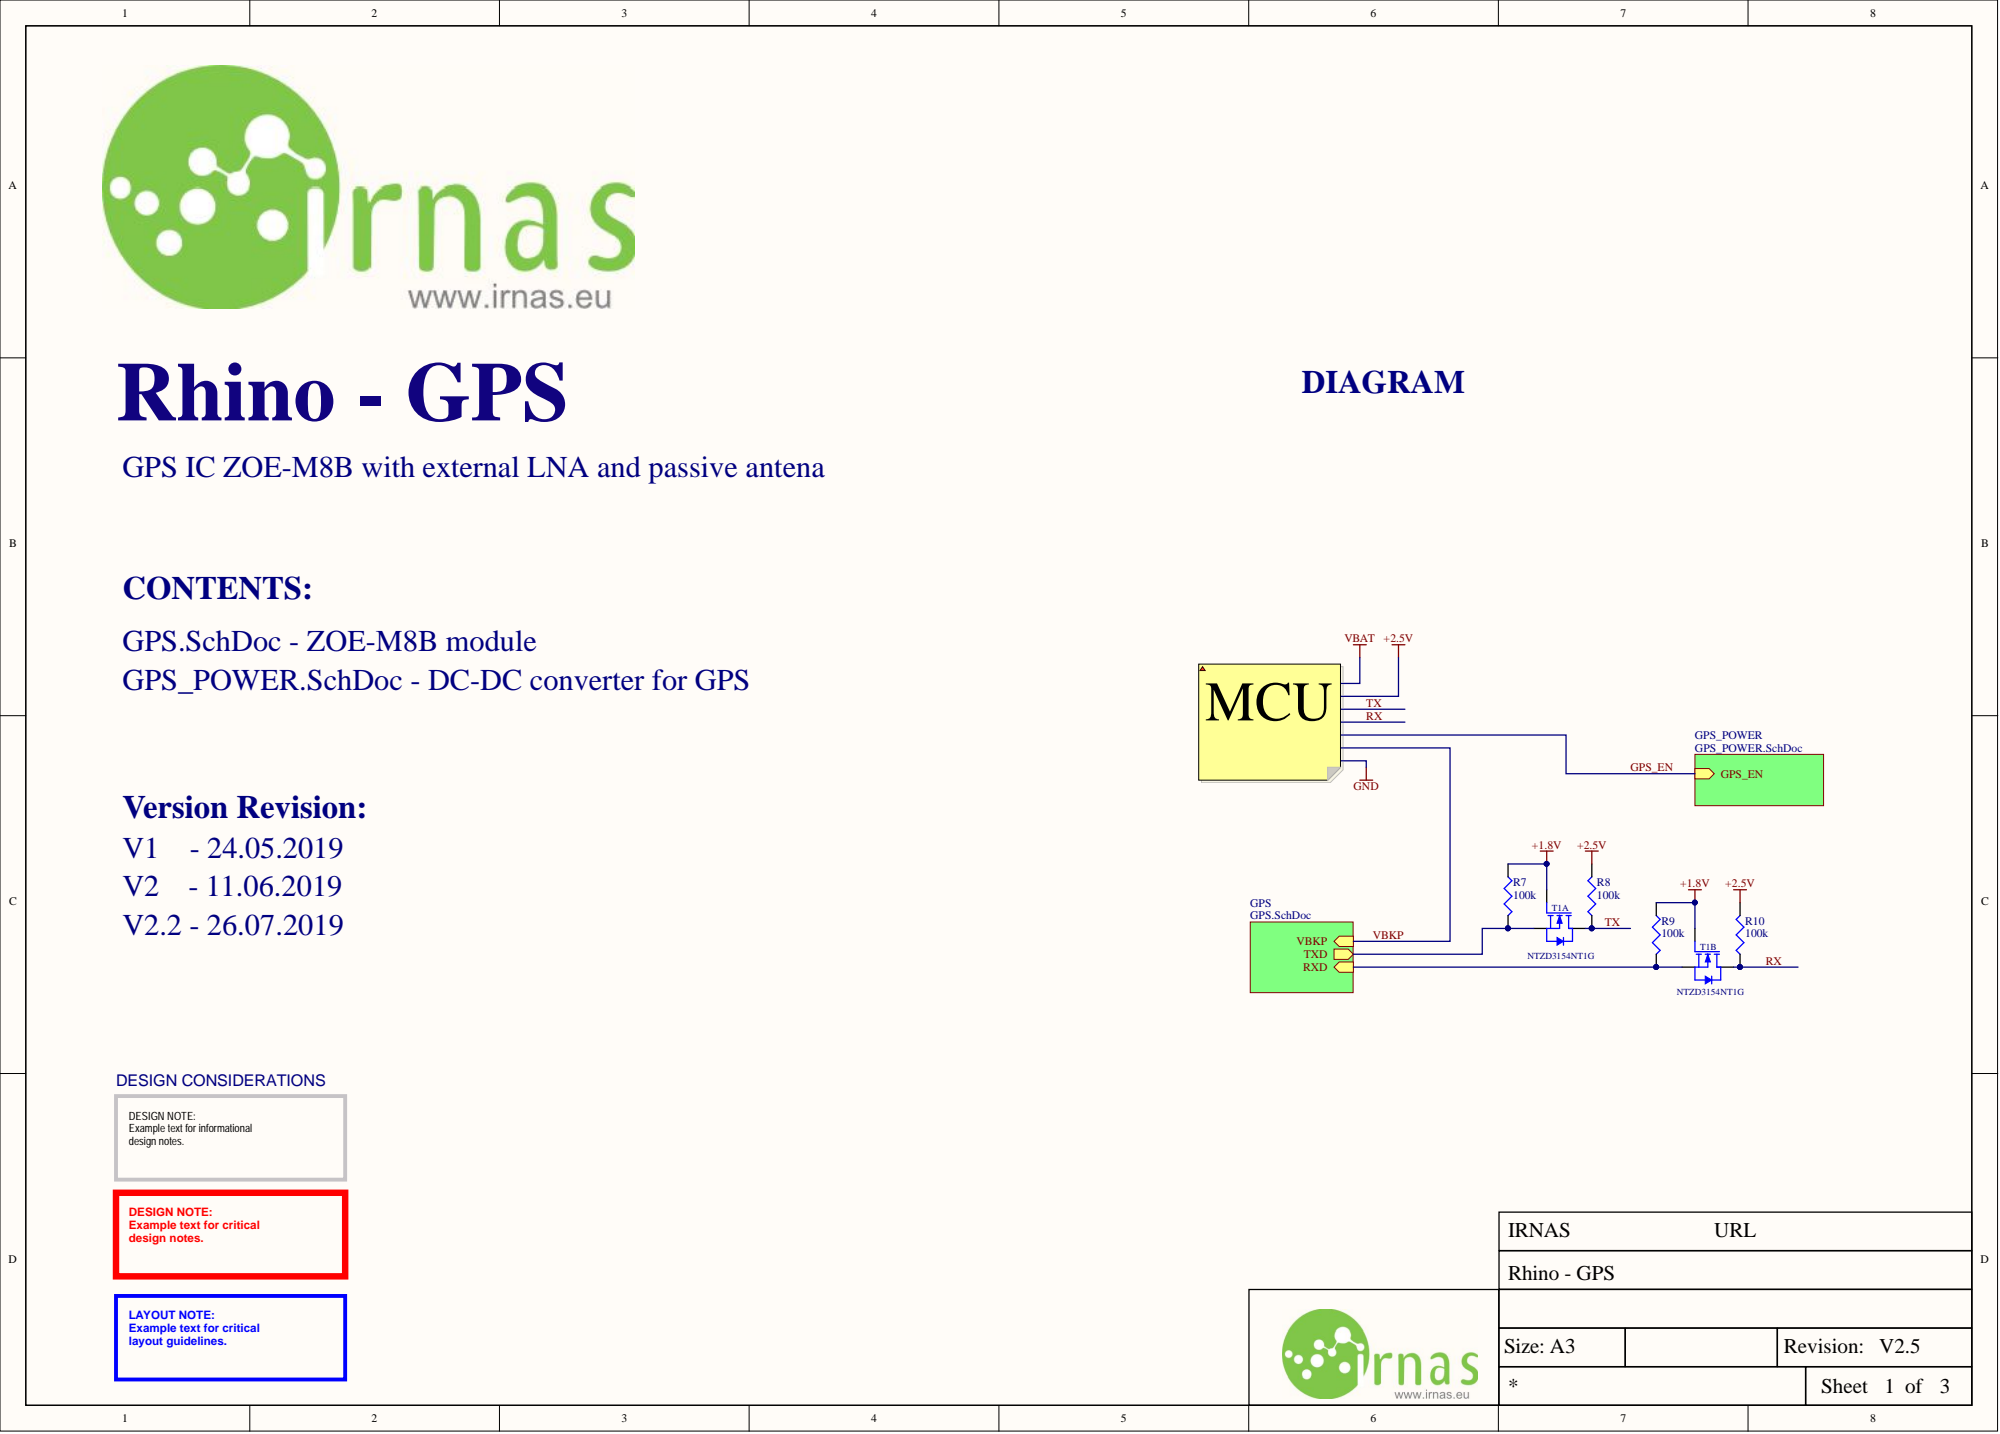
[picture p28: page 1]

GPS IC ZOE-M8B with external LNA and passive antena

GPS.SchDoc - ZOE-M8B module
GPS_POWER.SchDoc - DC-DC converter for GPS

DESIGN NOTE:
Example text for informational
design notes.

Example text for critical

LAYOUT NOTE:
layout guidelines.

Size: A3 | | Revision: V2.5

* | Sheet 1 of 3

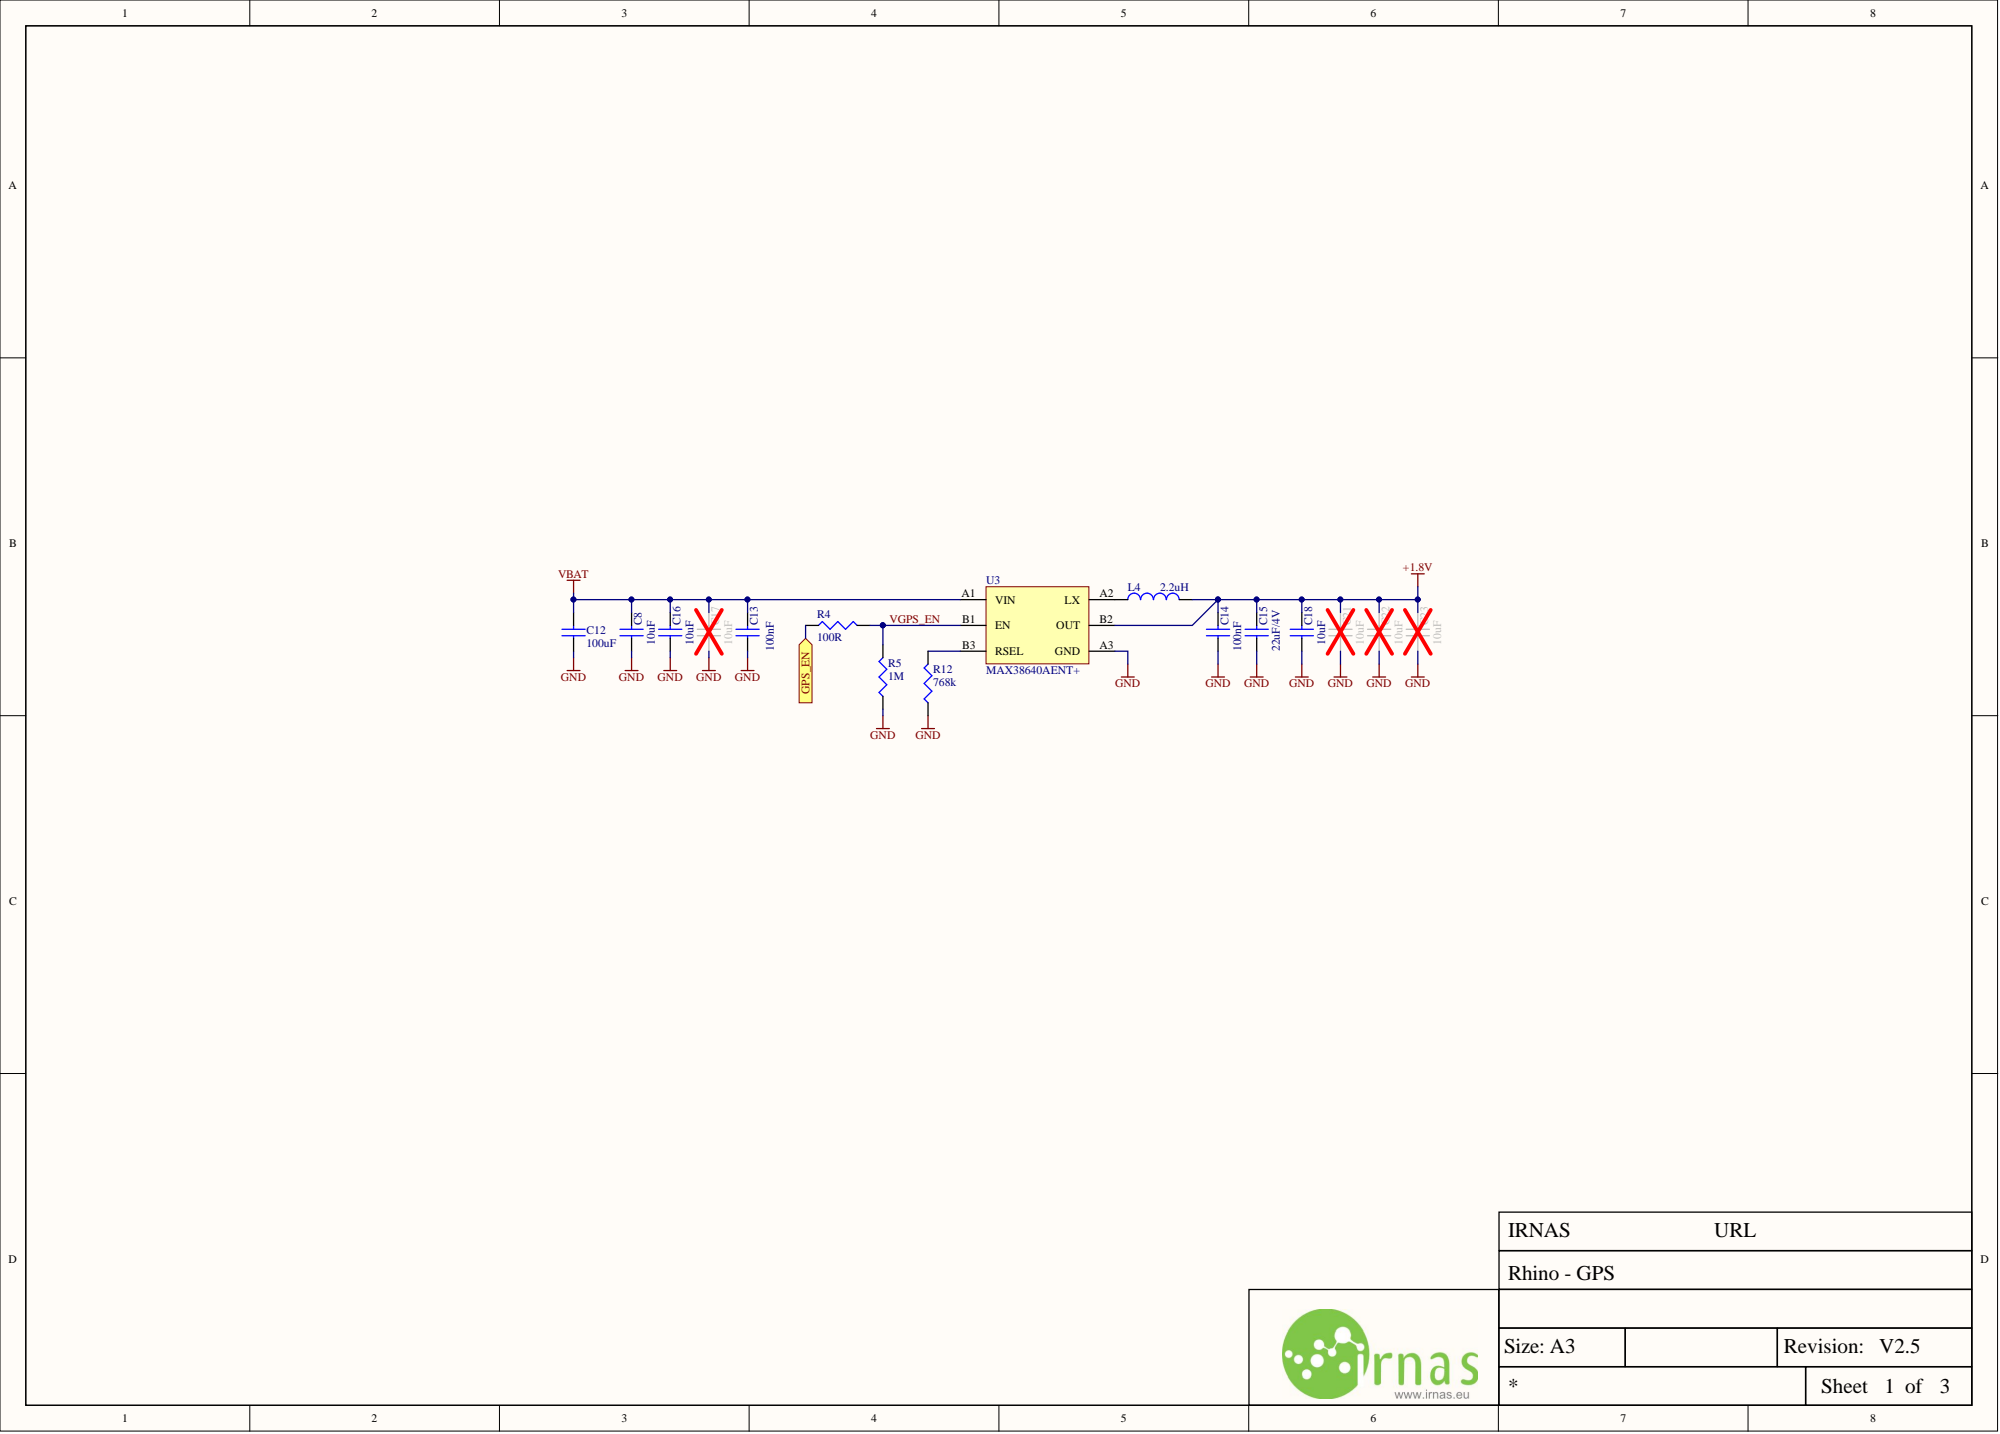
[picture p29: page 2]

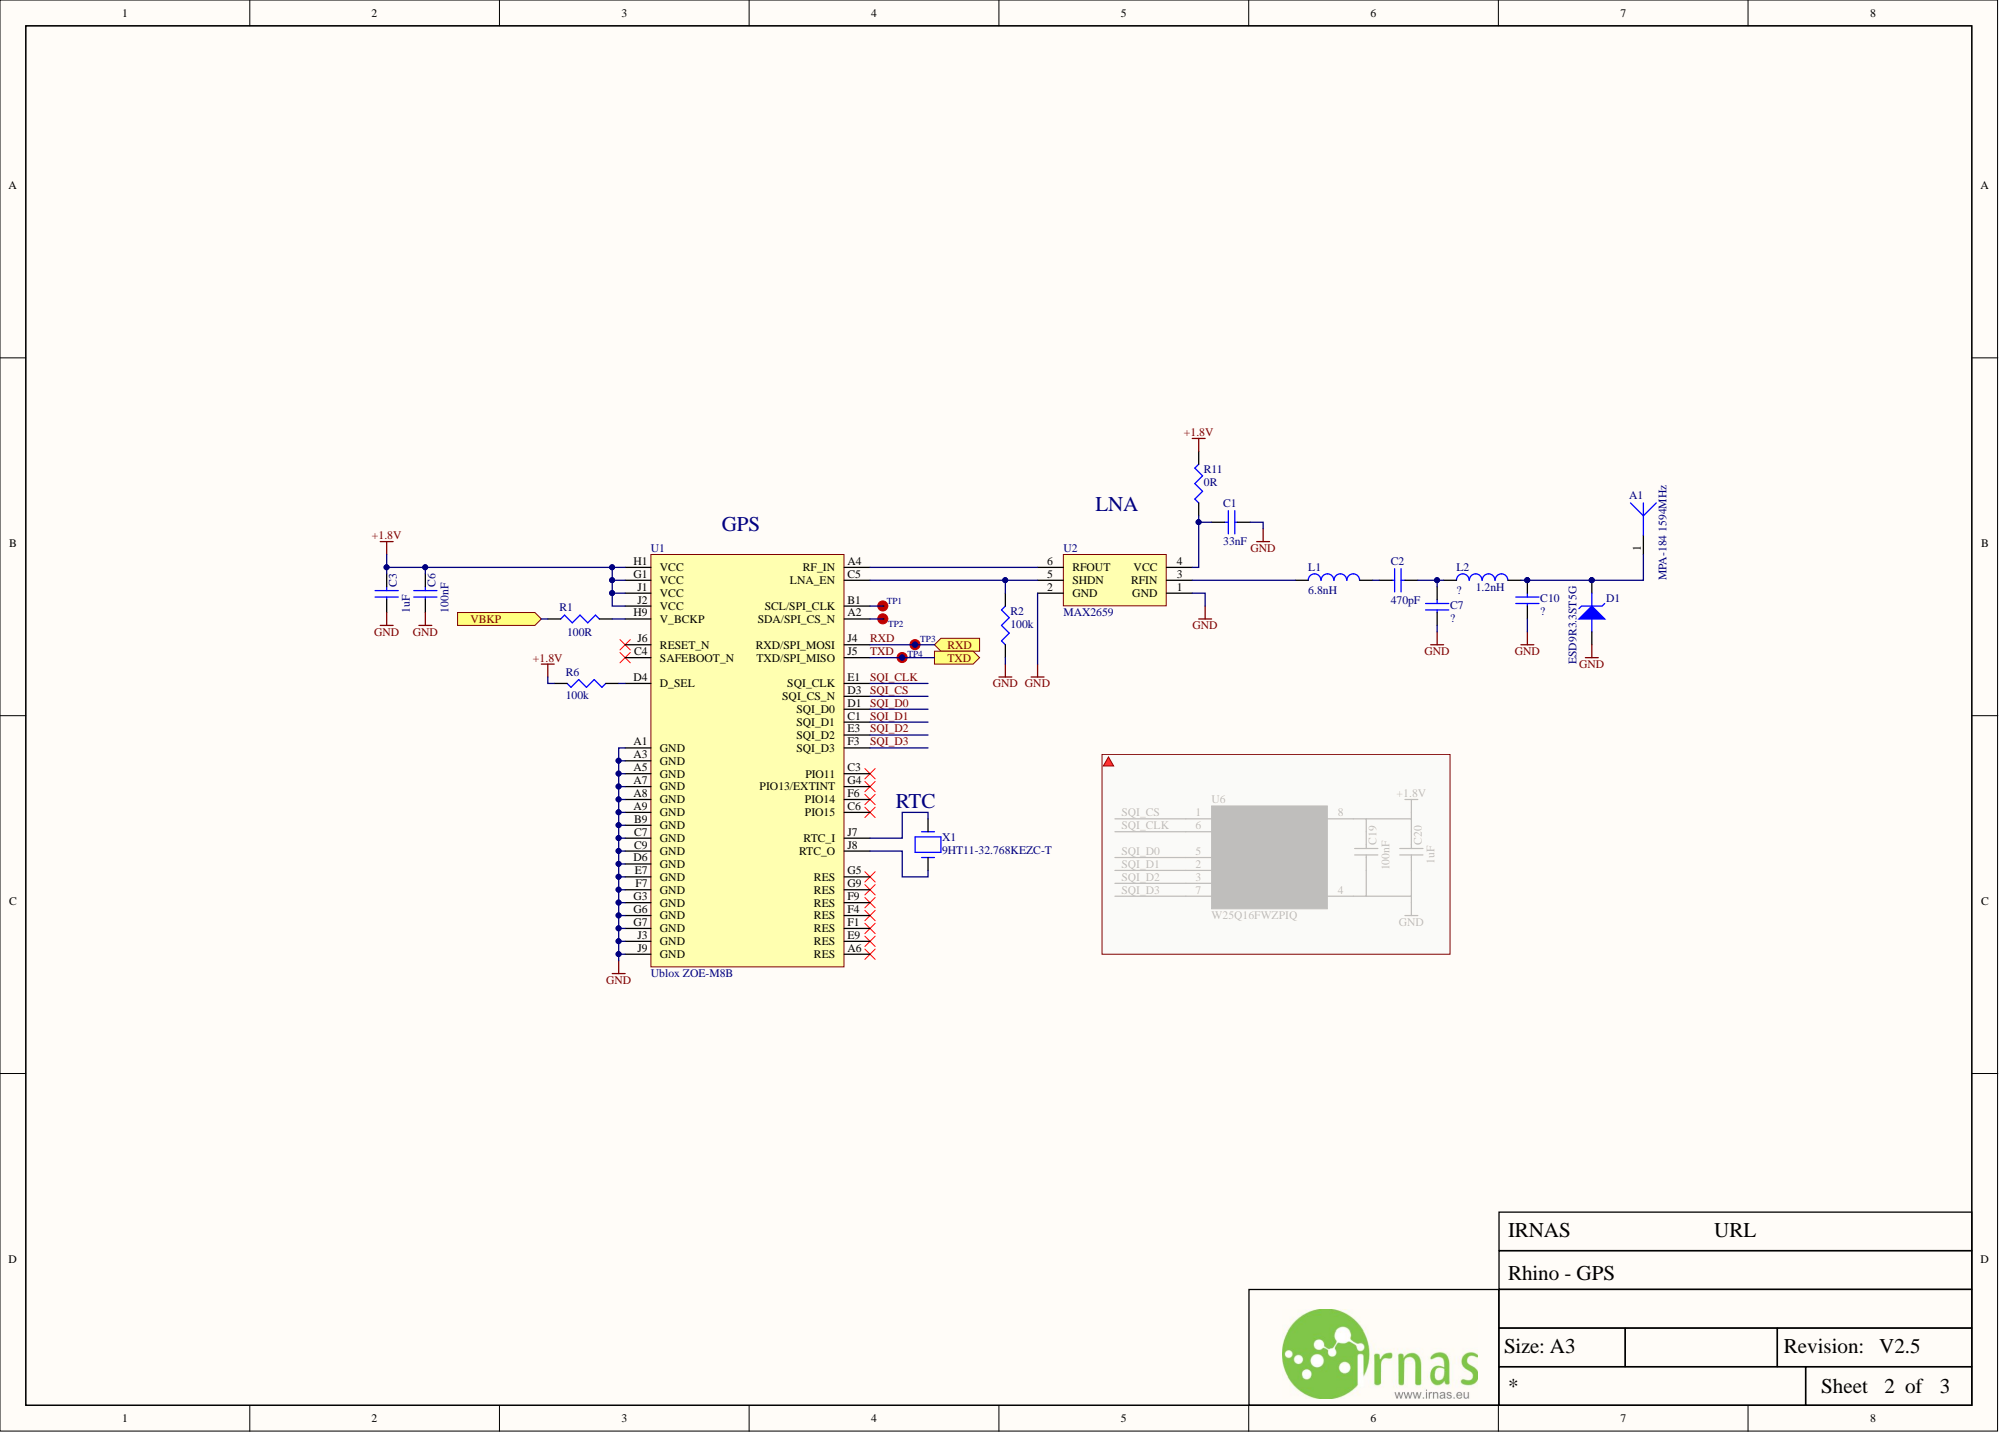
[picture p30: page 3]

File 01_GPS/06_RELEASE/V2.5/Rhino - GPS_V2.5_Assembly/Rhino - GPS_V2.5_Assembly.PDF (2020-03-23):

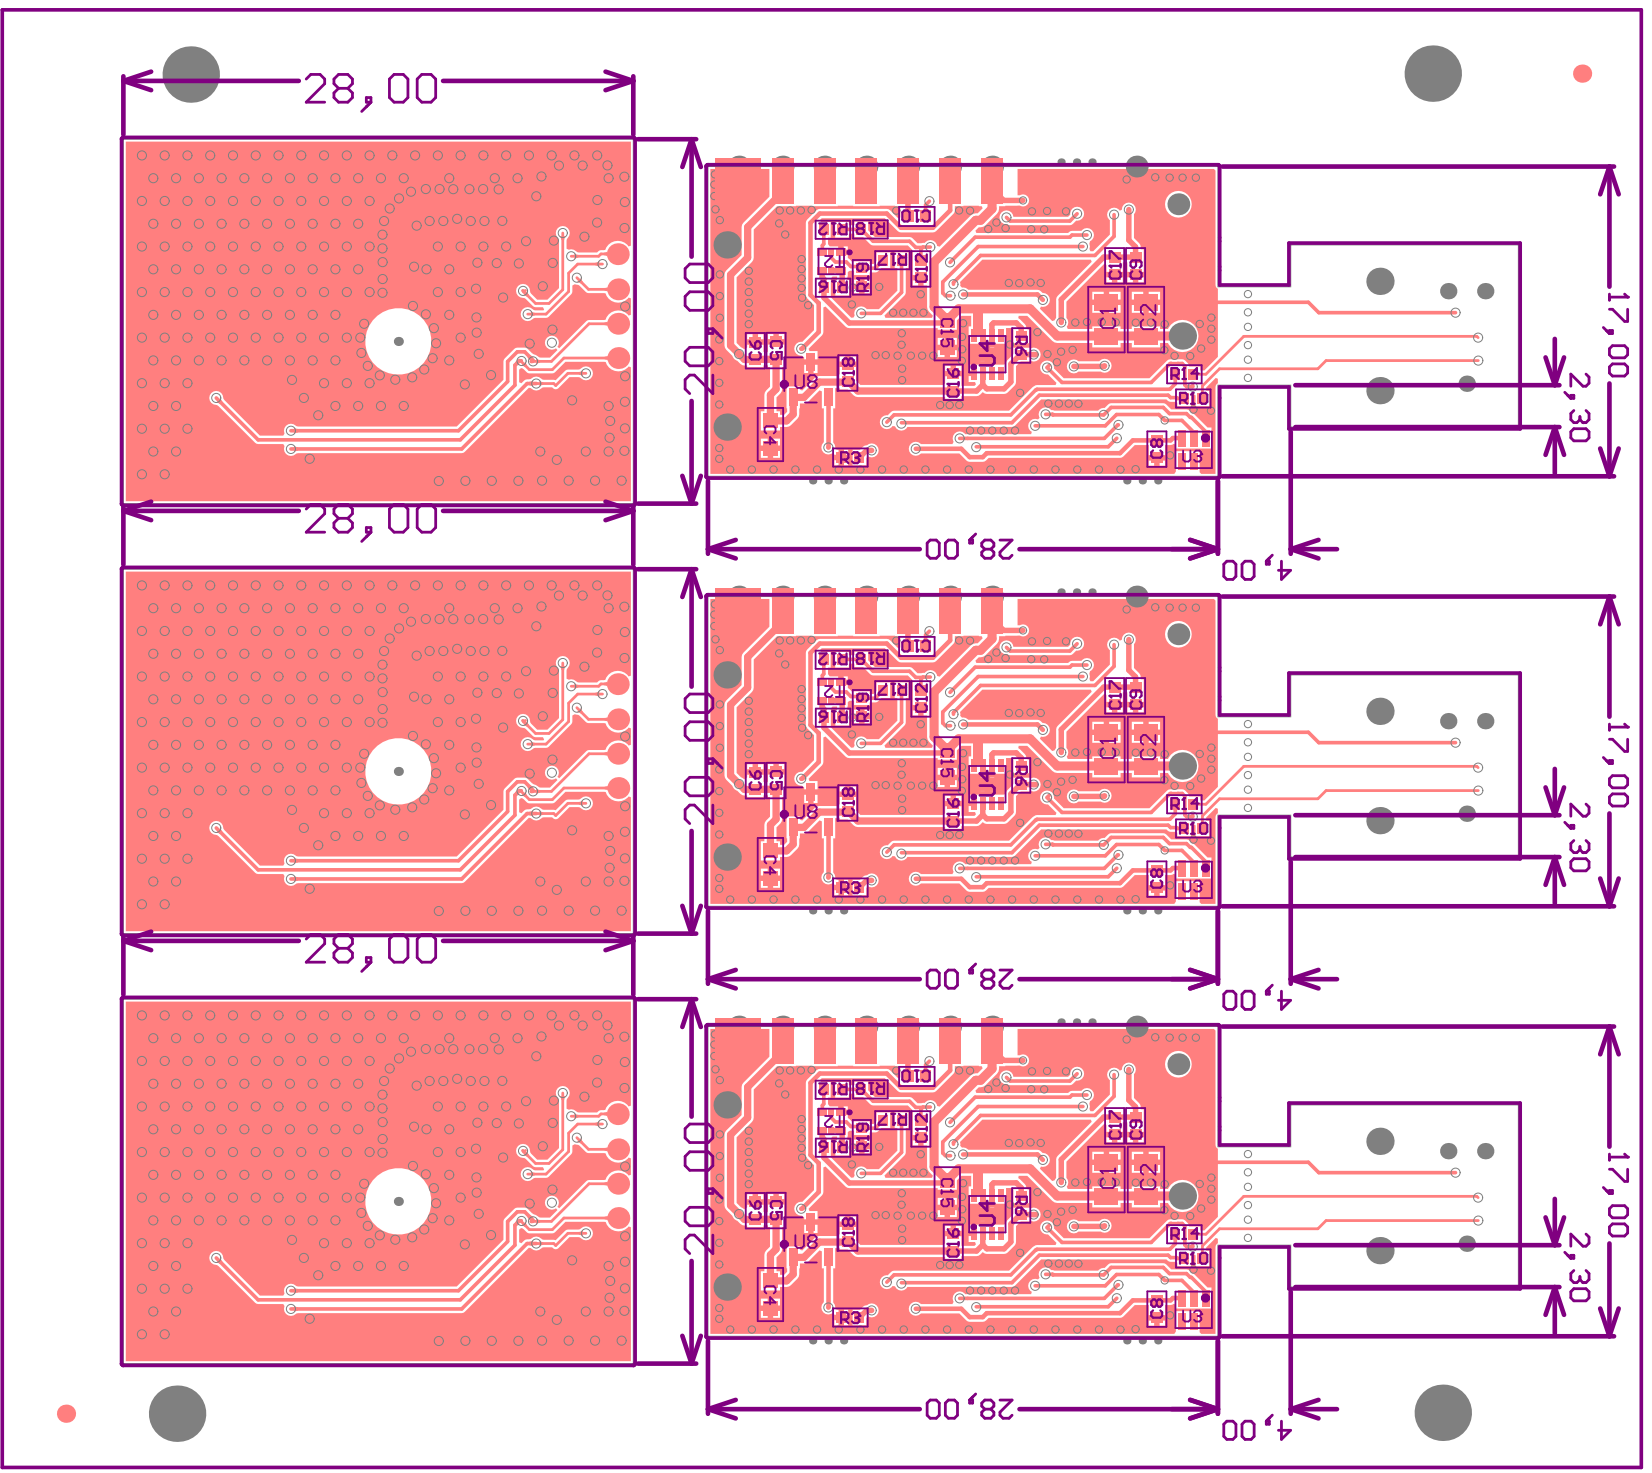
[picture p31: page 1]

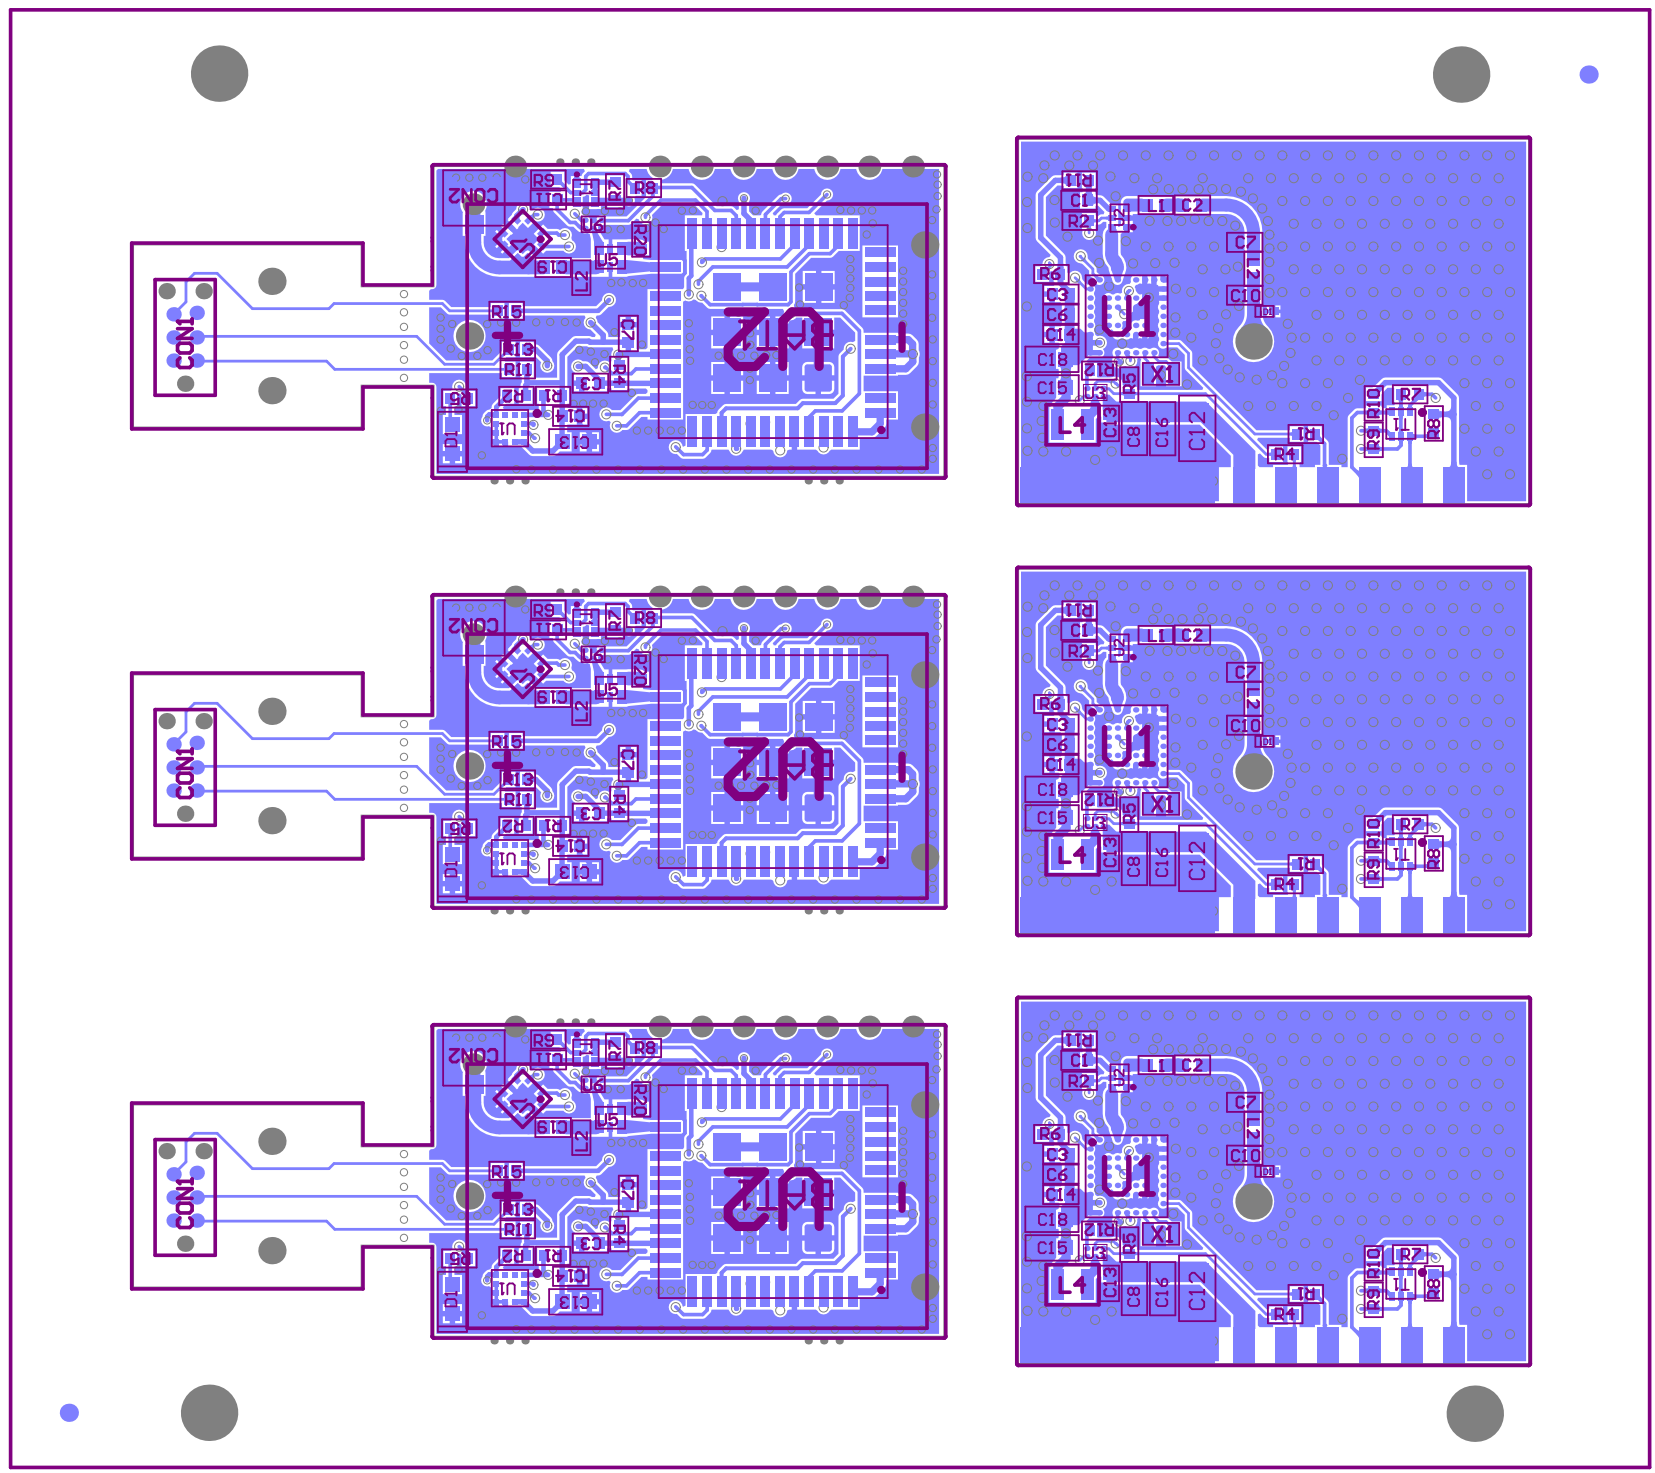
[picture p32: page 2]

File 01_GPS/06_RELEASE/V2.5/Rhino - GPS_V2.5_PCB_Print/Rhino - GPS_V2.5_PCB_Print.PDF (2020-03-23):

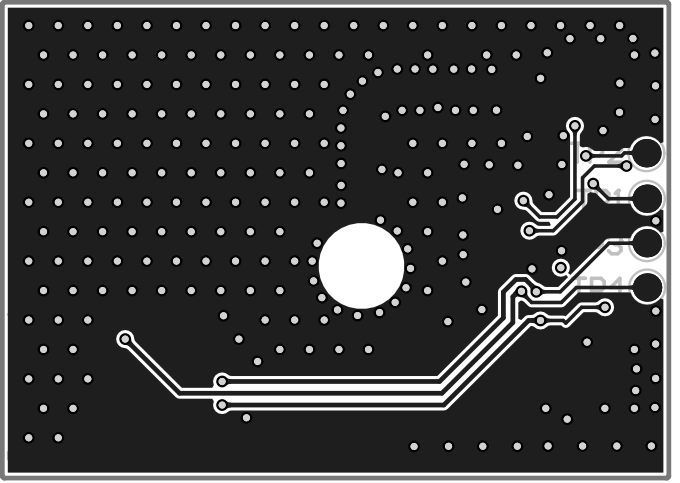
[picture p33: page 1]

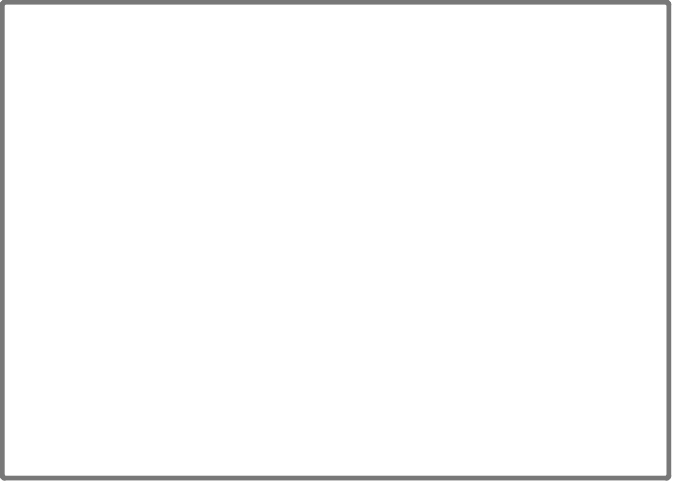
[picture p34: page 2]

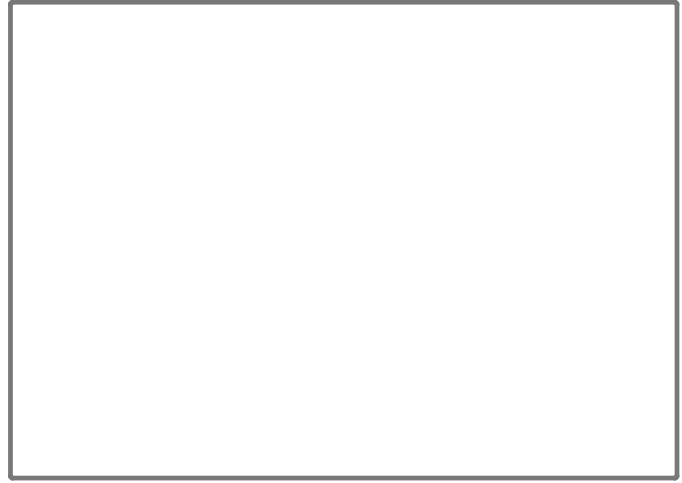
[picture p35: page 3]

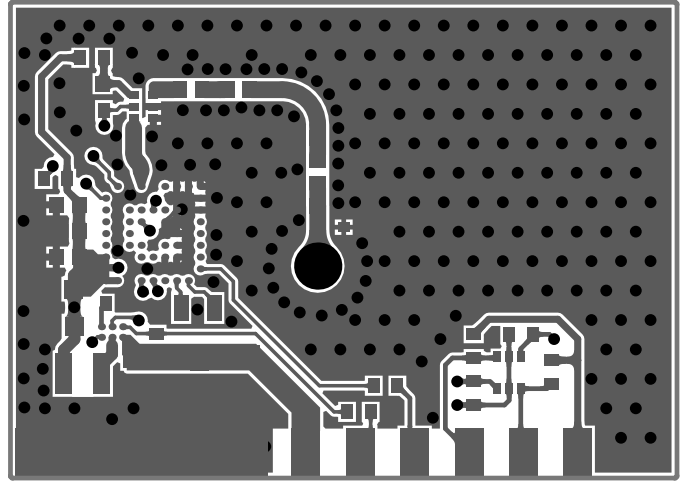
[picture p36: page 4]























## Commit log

2019-05-23 Projet first upload
    [01_GPS.PrjPCB, 02_SPACER_1.PrjPCB, 03_POWER.PrjPCB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]
2019-05-24 Remove unwanted directory
    [Rhino_panel.PcbDoc, Rhino_panel_s.PcbDoc]
2019-07-15 Remove duplicated directory
    [01_GPS.PrjPCB, GPS.PcbDoc, GPS.SchDoc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]
2019-07-15 Verison V2.1
    [01_GPS.PrjPCB, 02_MCU.PrjPCB, 03_LORA_ANT.PrjPCB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]
2019-07-15 Verison 2.1
    [01_GPS.PrjPCB, 02_MCU.PrjPCB, 03_LORA_ANT.PrjPCB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]
2019-07-15 Version 2.1
    [Rhino - GPS_V2.1_BOM.xlsx, Rhino - LORA ANT_V2.1_BOM.xlsx, Rhino - MCU_V2.1_BOM.xlsx]
2019-08-09 Version 2.2
    [01_GPS.PrjPCB, 02_MCU-ALEKSEJ.PrjPCB, 02_MCU.PrjPCB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]
2020-03-23 V2.5 update
    [01_GPS.PrjPCB, 02_MCU-ALEKSEJ.PrjPCB, 02_MCU.PrjPCB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]
